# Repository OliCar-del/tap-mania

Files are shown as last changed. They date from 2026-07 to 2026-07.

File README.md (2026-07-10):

# tap-mania

## Overview

**tap-mania** is a miniaturized arcade rhythm and dance game designed to be played with your fingers. Inspired by classic rhythm games like *Dance Dance Revolution*, *StepMania*, and *Guitar Hero*, tpmania brings the arcade experience to a desktop form factor.

Players follow rhythm cues displayed on a 16x4 LED matrix and must press the corresponding colored arcade buttons in time with the music. The game tracks your accuracy, calculates your score, and builds combo multipliers based on your timing.

## Features

* **Miniature Arcade Interface:** Four distinct arcade-style buttons (Red, Green, Blue, Yellow) with internal LED illumination, paired with a 16x4 RGB LED matrix to display incoming beats.
* **Standalone Gameplay:** Fully functional without a PC. Load your favorite `.wav` tracks and `.tsq` sequence files onto a microSD card, plug it in, and select your song using the built-in OLED display.
* **Audio Output:** Integrated 3.5mm audio jack with volume control, capable of driving standard 32-ohm headphones or speakers.
* **Dynamic Scoring & Combos:** Earn points based on timing accuracy (Perfect!, Good!, OK, Poor, Miss) and build up a combo counter for successive accurate hits.
* **Customizable Difficulty:** Connect the device to the tap-mania PC GUI to customize your timing windows (stored directly on the device's non-volatile memory).
* **Portable:** Powered by a rechargeable 3.7V LiPo battery with USB charging capabilities.

## Hardware Specifications

To build or understand the hardware architecture of tap-mania, the following core components are utilized:

* **Microcontroller / USB Interface:** Uses a primary MCU connected via a custom USB bridge (utilizing the `polyglot-turtle-xiao` firmware).
* **LED Matrix:** 16x4 WS2812B RGB LED matrix.
* **Buttons:** 4x illuminated arcade pushbuttons + dedicated control/navigation buttons (or optional rotary encoder/joystick).
* **Display:** OLED module for track selection and game statistics.
* **Storage:** MicroSD card module for reading audio (`.wav`) and beatmaps (`.tsq`).
* **Audio:** 16-bit / 44.1kHz (minimum) DAC for audio generation.
* **Power:** 3.7V LiPo battery with an integrated USB charging circuit.

## PC Companion Application

The tap-mania ecosystem includes a PC-based graphical user interface (GUI) that communicates with the device over USB.

**Using the GUI, you can:**

* **Manage Tracks:** Browse, add, and remove `.tsq` sequences and `.wav` audio files directly to/from the microSD card.
* **Tweak Game Settings:** Adjust the exact millisecond timing windows for scoring (e.g., changing a "Perfect!" window from the default 200ms). These settings are saved to the device's internal memory.
* **View Track Metadata:** Read song names, artists, difficulty levels, BPM, and track length.

## How to Play

1. **Select a Track:** Use the onboard navigation buttons and OLED screen to pick a song from the SD card.
2. **Watch the Matrix:** The 16x4 LED matrix will show colored indicators falling towards the bottom of the screen.
3. **Tap to the Beat:** When the colored indicators reach the bottom of the matrix, the corresponding arcade buttons will light up. Press the buttons to the beat!
4. **Hold Notes:** If the LEDs show white indicators, hold the corresponding button down for the duration of the note.

**Scoring System:**

* **Perfect!**: +50 points (Default: ±100ms)
* **Good!**: +20 points (Default: ±150ms)
* **OK**: +10 points (Default: ±200ms)
* **Poor**: 0 points (Default: ±250ms)
* **Miss**: -10 points (Missed entirely, or pressed outside windows)

*Note: Your score cannot drop below zero. Missing notes will reset your active combo counter.*

## Custom Sequences (.tsq Format)

tap-mania uses a custom, lightweight text format for its beatmaps (`.tsq`).

### File Structure

A `.tsq` file consists of a header and a sequence body.

```text
Name: Song Title
Artist: Artist Name
BPM: 120
Difficulty: HARD
Offset: 500
---

```

* **BPM** must be between 90 and 220.
* **Difficulty** and **Offset** (delay in ms before the first beat) are optional.

### Sequence Data

Following the `---` divider, the beatmap uses a simple grid layout representing the 4 buttons (Red, Green, Blue, Yellow).

* `0` = No press
* `1` = Tap
* `2` = Hold (Hold starts on the first `2` and releases on the final `2` in a column)

Sequences are grouped into "bars" of 4 rows (or 8 rows for half-beats), separated by commas.

```text
1000
0100
0010
0001
,
2000
2000
0000
0000
;

```

*The file must end with a semicolon (`;`). Any audio file associated with the beatmap must share the exact same filename (e.g., `song.tsq` and `song.wav`) and be placed on the SD card.*

> ## Deep Dive Documentation
If you are looking to understand the internal workings of tap-mania, modify the codebase, or review the hardware design, please refer to our detailed documentation:

* 🧠 [Software Architecture & Execution Flow](ARCHITECTURE.md) - Details on the internal state machine, FatFs implementation, scoring logic, and hardware abstraction.
* ⚡ [Hardware & PCB Design](HARDWARE.md) - Details on the Altium schematics, power delivery (LiPo/USB), and signal routing.

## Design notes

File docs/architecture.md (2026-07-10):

---

# Architecture and Code Execution Summary

## 1. System Architecture Overview

The firmware is designed for an **STM32L433** microcontroller (configured via STM32CubeMX/IDE and built using a CMake workflow). It functions as a real-time embedded system that bridges low-latency hardware peripherals (timers, audio generation, button interrupts, and addressable LEDs) with a file system layer for standalone game execution, alongside a USB serial command link for configuration management.

```
                  +---------------------------------------+
                  |               Main Loop               |
                  |     (Game States, Menu, Execution)     |
                  +-------------------+-------------------+
                                      |
         +----------------------------+----------------------------+
         |                            |                            |
         v                            v                            v
+-----------------+          +-----------------+          +-----------------+
| System Drivers  |          |  Game Modules   |          | Data/Interfaces |
| - Audio (SAI)   |          | - TSQ Parser    |          | - FatFs (SD)    |
| - ARGB Matrix   |          | - Hit Scoring   |          | - Flash Storage |
| - Debounce/Int  |          | - State Control |          | - USB Serial    |
+-----------------+          +-----------------+          +-----------------+

```

---

## 2. Code Modules & Component Breakdown

### Core Game Engine & Parsing

* **`tsq_parser.c` / `tsq_parser.h**`
Responsible for streaming and parsing the custom `.tsq` rhythm sequence text files from the filesystem. It parses the metadata header (Name, Artist, BPM, Difficulty, and Beat Offset) and sequentially processes bars of row strings (`0`, `1`, `2`) to interpret taps, multi-presses, and hold notes.
* **`game_state.c` / `game_state.h**`
Manages the primary operational state machine of the machine (e.g., `MENU`, `SONG_SELECT`, `PLAYING`, `RESULTS_SCREEN`). It handles transitions, restarts, and game over sequences.
* **`scoring.c` / `scoring.h**`
Processes timing parameters down to the millisecond. When a hardware input event triggers, this module calculates the delta between the ideal beat-time and the actual player button press, mapping it to specific accuracy classifications (*Perfect!*, *Good!*, *OK*, *Poor*, *Miss*) and updates the total score and combo counters.

### Hardware Interface & Drivers

* **`audio.c` / `audio.h**`
Controls the monoaural audio stream. It interacts with the audio subsystem (likely utilizing the Serial Audio Interface — SAI or DAC via DMA) to read `.wav` data structures from the storage media, handling the configured audio latency offsets to match physical beats perfectly.
* **`ARGB.c` / `ARGB.h` & `led_display.c` / `led_control.c**`
Provides an optimized low-level driver for the addressable 16x4 WS2812B RGB LED matrix. It converts structural step paths into timed NRZ serial signals (often over SPI or TIM+DMA) to animate oncoming steps down the lane while dynamically lighting up the internal button LEDs.
* **`SH1106.c` / `SH1106.h` & `fonts.c**`
A hardware display driver targeting the I2C/SPI based SH1106 OLED module. It handles character arrays and coordinate plotting for system menus, song selections, and operational statistics.
* **`button_handler.c`, `button_debounce.c`, `config_input.c**`
Handles the asynchronous input processing. Pin interrupts generated by the four primary illuminated arcade switches and auxiliary controls are debounced using soft timers before being dispatched to the step engine.

### Subsystems & Connectivity

* **`sd_card_utils.c` / `sd_card_detect.c**`
Integrates the **FatFs** middleware platform directly above hardware SPI/SDMMC layers to interface reliably with external microSD cards containing song packs.
* **`config_storage.c`**
Implements a persistent storage system to save personalized device configurations (like customized user timing windows between 1ms and 500ms) within the STM32's internal non-volatile Flash memory pages.
* **`command_handler.c` / `uart_debug.c**`
Processes incoming serial streams passing through the USB interface (interfacing with the external USB microcontroller bridge). It maps PC-side adjustments into executable variables, allowing communication with the companion configuration GUI application.

---

## 3. Firmware Execution Flow

The program life cycle maps into three operational phases:

### Phase A: Initialization

1. **System Init:** Hardware abstraction layers (`HAL_Init`) configure internal phase-locked loops (PLLs) to supply stable clock lines across communication lines and compute registers.
2. **Peripheral Init:** Resets and schedules interfaces for internal systems (FatFs for SD card access, I2C/SPI for the SH1106 OLED, Timer channels for PWM/DMA LED patterns, and sound peripherals).
3. **Config Extraction:** Reads the internal Flash non-volatile space to extract customized game latency parameters. If blank, it initializes system default timings.
4. **Storage Verification:** Attempts to mount the microSD interface. If the card is missing or corrupted, a critical alert prints directly to the display loop.

### Phase B: Game Loop Execution

Once running, the main loop continually tracks operational events:

* **State Control:** Monitors current selections. If navigating menus, it decodes button ticks to cycle through parsed song variables.
* **Rhythm Mode Processing:** Upon starting a track, the processor synchronizes audio tracks with a master tick timer. The engine matches the song's BPM to periodically step row data forward, moving rows across the 16x4 matrix.
* **The Beat LED Window:** A software event schedules the hardware Beat LED to flash precisely `50ms` before the beat hits, cutting power `50ms` afterward.
* **Input Capture:** If a player triggers a button, an interrupt logs a timestamp. The delta between this click and the current track timing index is measured by `scoring.c` to assign score weightings instantly.

### Phase C: Communication & Interventions

* **UART Intercepts:** Asynchronous USB data packets from the PC GUI drop into ring buffers. `command_handler.c` executes these actions out of the game's critical loop (e.g., retrieving configuration lists or committing new timing windows directly to Flash).

---

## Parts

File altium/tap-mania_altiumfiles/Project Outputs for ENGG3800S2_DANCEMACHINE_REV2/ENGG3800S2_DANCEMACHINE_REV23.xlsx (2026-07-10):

Designator | Description | Quantity | Price each | Total price | Manufacturer | Manufacturer # | Supplier | Supplier # | RoHS link
U1 | 0.9-5V Step down DC/DC module | 1 | $4.74 | $4.74 | Murata Power Solutions | OKL-T/1-W12N-C | Digikey | 811-2260-1-ND | https://www.digikey.com.au/product-detail/en/murata-power-solutions-inc/OKL-T-1-W12N-C/811-2260-1-ND/2605211
U2 | Global shutter CMOS sensor | 1 | $178.32 | $178.32 | On Semiconductor | NOIP1FN1300A-QTI | Mouser | 863-NOIP1FN1300A-QTI | https://au.mouser.com/ProductDetail/ON-Semiconductor/NOIP1FN1300A-QTI
C1, C2 | 0.1uF 0603 capacitor, X7R, 10% | 2 | $0.41 | $0.83 | Taiyo Yuden | TMF107B7104KAHT | Mouser | 963-TMF107B7104KAHT | https://au.mouser.com/ProductDetail/Taiyo-Yuden/TMF107B7104KAHT
 |  |  | Total: | $183.89

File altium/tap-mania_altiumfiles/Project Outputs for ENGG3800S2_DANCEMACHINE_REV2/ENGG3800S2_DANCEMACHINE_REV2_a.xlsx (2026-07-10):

Comment | Description | Designator | Footprint | LibRef | Quantity
SEEEDUINO | SAMD21 Microcontroller Development Board 0.0327MHz/48MHzCPU 32KB RAM 256KB Flash | *1 | XIAO - 6mm annular | SEEEDUINO | 1
0.1uF | Capacitor CAP CER 0.1UF 25V X7R 0402 CL05B104KA5NNNC | C1, C2, C3, C4, C5, C12, C13, C15, C16, C17, C19, C25, C37, C38, C39, C40, C41, C42 | CAPC1005X55N | CL05B104KA5NNNC | 19
CAP/0603 | Ceramic Capacitor;16V;X7R;0603;, Ceramic Capacitor;50V;C0G;0603; 100pF, Ceramic Capacitor;25V;X7R | C6, C8, C9, C10, C12, C14, C16 | CAP/0603 | 07.0043, 07.0138, 07.0772, 07.0053 | 7
CAP/1206 | Ceramic Capacitor;10V;X7R;1206, Ceramic Capacitor;25V;X5R; | C7, C11, C13, C15, CBATT1, CIN1, CSYS1 | CAP/1206 | 07.0581, 07.0752 | 7
4.7uF | 860020672008 WCAP-ATG5 Aluminum Electrolytic Capacitors860020672008 | C14 | WCAP-ATG5_D5H11 | CMP-03913-53914231-1 | 1
1uF | Capacitor 1 µF ±10% 25V Ceramic Capacitor X7R 0603 (1608 Metric) CL10B105KA8NNNC | C17, C18, C21 | CAPC1608X90N | CL10B105KA8NNNC | 4
10nF ±10% 16V X7R | Capacitor 10000 pF ±10% 16V Ceramic Capacitor X7R 0603 (1608 Metric) ETSG 64-12-01 C0603C103K4RECTU | C19 | C0603 | C0603C103K4RECTU | 1
0.1 uF, +/- 10%, 50 V | Chip Capacitor, 0.1 uF, +/- 10%, 50 V, -55 to 125 degC, 0603 (1608 Metric), RoHS, Tape and Reel | C20, C22 | CAPC1608X90X35ML10T15 | CMP-2100-03643-1 | 2
10UF 16V X7R | CAP CER 10UF 16V X7R 0805 CL21B106KOQNNNE | C21, C24, C36 | FP-CL21B106KOQNNNE-MFG | CMP-2000-06106-2 | 3
1 µF ±10% 25V | Capacitor 1 µF ±10% 25V Ceramic Capacitor X7R 0603 (1608 Metric) CL10B105KA8NNNC | C23 | CAPC1608X90N | CL10B105KA8NNNC | 1
I2C OLED Display | OLED_I2C_4pinHEADER Large clear space | DISP1 | OLED_I2C_4pinHEADER | OLED_I2C_4pinHEADER | 1
0ZCG0300FF2B | Fuse | F1 | FUSC4632X155N | 0ZCG0300FF2B | 1
FBMH1608HM601-T | Ferrite Bead | FB1 | BEADC1608X90N | FBMH1608HM601-T | 1
Fiducial Mark | Small 1mm/40mil pad with 40mm soldermask clearance | FID1, FID2, FID3, FID4 | FIDUCIAL_SMALL | FIDUCIAL_SMALL | 4
Mounting Hole | M3 Mounting hole (3.4mm) | H1, H2, H3, H4 | M3_MOUNTING_HOLE_3_4_mm | M3_MOUNTING_HOLE | 4
TPD8S300ARUKR | Integrated Circuit | IC1 | QFN40P300X300X80-21N-D | TPD8S300ARUKR | 1
3220-10-0100-00 | Connector | J1 | 322010010000 | 3220-10-0100-00 | 1
JST_PH 2.0 Male Header | Male Header, Pitch 2 mm, 1 x 2 Position, Height 6 mm, Tail Length 3.4 mm, -25 to 85 degC, RoHS, Bulk B2B-PH-K-S(LF)(SN) | J1 | JST-B2B-PH-K-S_V | CMP-2000-05162-1 | 1
USB4105-GF-A | CONN RCPT USB2.0 TYPEC 5A | J2 | FP-USB4105-GF-A-MFG | CMP-245163-000001-1 | 1
0022285034 | Connector | J4 | 0022285034 | 0022285034 | 1
Micro SD | ETSG | J5 | SD CARD | SD_CARD_MICRO | 1
2.8mm Terminal | 2.8mm Spade Lug Connector 1742428-1, Connector 1742428-1 | J6, J7, J8, J9, J10, J11, J12, J13, J14 | 17424281 | 1742428-1 | 9
CONN HEADER VERT 1POS 2.54MM | CONN HEADER VERT 1POS 2.54MM PH1-01-UA | JAGND1, JPGND1 | FP-PH1-01-UA-MFG | CMP-42765-000003-1 | 2
2.2 uH, +/- 30%, 6.3 A | Semi-Shielded Power Inductor, 2.2 uH, +/- 30%, 6.3 A, -40 to 125 degC, 2-Pin SMD, RoHS, Tape and Reel SRN8040-2R2Y | L1 | BOUR-SRN8040_V | CMP-2000-07144-1 | 1
LED/SMD/0805 | LED;ºì¹â; | LED1 | LED/SMD/0805 | 19.0003 | 1
MCL-S270SRC | LED | LED2, LED4 | LEDC2012X90N | MCL-S270SRC | 2
61300211121 |  | P1, P2, P3, P4 | 61300211121 | CMP-1712-00002-6 | 6
4.7 KOhm, +/- 1%, 0.1 W | Chip Resistor, 4.7 KOhm, +/- 1%, 0.1 W, -55 to 155 degC, 0603 (1608 Metric), RoHS, Tape and Reel RC0603FR-074K7L | R1, R2, R3, R4, R5, R39, R40, R41, R42 | SURFM RESISTOR | 0805-R | 9
RES/0603 | Film Resistor;1%;, Film Resistor;5%;, Film Resistor;5%;1/10W, Film Resistor;1% | R6, R7, R8, R9, R10, R11, R12, R13, RH1, RISET1, RL1, ROLM1, RT1, RT2, RT3 | RES/0603 | 06.0160, 06.0112, 06.0691, 06.0129, 06.0284, 06.0015, 06.0148, 06.0177, 06.0182, 06.0039 | 15
30 Ohm | Resistor ERJPA3F30R0V 30 Ohms ±1% 0.333W, 1/3W Chip Resistor 0603 (1608 Metric) Automotive AEC-Q200, Pulse Withstanding Thick Film | R8, R12, R31, R32, R33 | RESC1608X55N | ERJPA3F30R0V | 5
510 Ohm | RES Thick Film, 510Ω, 1%, 0.125W, 100ppm/°C, 0805 CRCW0805510RFKEA | R13, R43 | FP-CRCW0805-e3-IPC_B | CMP-2001-03989-2 | 2
5.1K OHM 1% 1/10W | [NoValue], RES 5.1K OHM 1% 1/10W 0603 RC0603FR-075K1L | R14, R15 | RESC1608X55X25ML10T15 | CMP-2000-04091-1 | 2
10kOhm | Resistor RES 10K OHM 5% 1/8W 0805 RC0805JR-0710KL | R14, R25, R26, R27, R28, R29, R30 | RESC2012X60N | RC0805JR-0710KL | 7
1 MOhms ±0.1% 0.125W | 1 MOhms ±0.1% 0.125W, 1/8W Chip Resistor 0805 (2012 Metric) Anti-Sulfur, Automotive AEC-Q200 Thin Film | R16 | RESC2012X50N | RG2012P-105-B-T5 | 1
100kΩ, 0.1%, 0.125W | RG2012P-104-B-T5Automotive Metal Thin Film Chip Resistor, 0805, 100kΩ, 0.1%, 25ppm/°C, 0.125W, 150V | R17, R41, R42 | FP-RG2012-IPC_B | CMP-2001-02710-2 | 3
1kΩ ±1% 0.125W | 1kΩ ±1% 0.125W 0603 High Power Anti-Sulfur Thin Film Chip Resistor RNCP0603FTD1K00 | R34 | FP-RNCP0603-IPC_A | CMP-26527-006179-1 | 1
330 Ohms ±1% 0.125W | RK73H1JTTD3300F 330 Ohms ±1% 0.125W, 1/8W Chip Resistor 0603 (1608 Metric) Automotive AEC-Q200 Thick Film | R35, R36, R37, R38 | RESC1608X55X30ML20T10 | CMP-2000-01422-1 | 4
90kOhm | Film Resistor;1%; RES/0603 MCT06030C9102FP500 | RILIM1 | RES/0603 | 06.0129 | 1
RES/1206 | Film Resistor;1% | RS1 | RES/1206 | 06.0564 | 1
Solder Bridge | Tension Fill Solder Bridge | SB1, SB2, SB3, SB4, SB7, SB8, SB9 | SOLDER BRIDGE OPEN SMALL | SOLDER_BRIDGE_TDROP | 9
1825910-6 | Tact Switch, SPST-NO, 0.05 A, -35 to 85 degC, 4-Pin THD, RoHS, Bulk | SW1, SW2, SW3, SW5, SW6 | TECO-1825910-6_V | CMP-1684-00021-1 | 5
JS5208 | Switch | SW4 | JS5208 | JS5208 | 1
DPST | SW-T2-3A-A-A2-M2 | SW7 | SWITCH_PANELMOUNT | SWITCH_PANEL MOUNT | 1
Small testpoint 40mil | 40mil circular pad no hole | TP1, TP2, TP3, TP4, TP5 | TEST_POINT_SMALL | TEST_POINT_SMALL | 5
MP2637 |  | U1 | QFN24/4X4 | MP2637 | 1
STM32L433CCT6 - 48LQFP | IC MCU 32BIT 256KB FLASH 48LQFP | U1 | FP-LQFP48-5B-MFG | CMP-12105-000047-1 | 1
AP2112K-3.3TRG1 | IC REG LINEAR 3.3V 600MA SOT25 | U2 | FP-SOT25-MFG | CMP-12756-000035-1 | 1
MAX98357AETE+T | IC AMP CLASS D MONO 3.2W 16TQFN | U3 | FP-T1633-4-IPC_B | CMP-05698-000018-1 | 1
SJ1-3513N | Undefined or Miscellaneous | U4 | SJ13513N - stubby silk | SJ1-3513N | 1

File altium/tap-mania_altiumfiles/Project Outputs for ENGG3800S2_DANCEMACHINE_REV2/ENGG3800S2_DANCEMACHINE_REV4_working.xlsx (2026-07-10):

Comment | Description | Designator | Footprint | LibRef | Quantity
NC |  | [NoValue], *? |  | NC | 10
0.1µF, ±10%, 25V, X7R | Capacitor CAP CER 0.1UF 25V X7R 0402 CL05B104KA5NNNC | C1, C2, C3, C4, C5, C28, C30, C37, C38, C39, C40, C41, C42 | CAPC1005X55N | CL05B104KA5NNNC | 13
NC(1µF, ±10%, 25V, X7R) | Ceramic Capacitor;16V;X7R;0603; | C6 | CAP/0603 | 07.0043 | 1
22µF, ±10%, 25V, X7R | Ceramic Capacitor;10V;X7R;1206, Ceramic Capacitor;10V;X7R;1206; 22µF, ±10%, 25V, X7R, Ceramic Capacitor;25V;X5R; | C7, C13, CBATT1, CIN1, CSYS1 | CAP/1206 | 07.0581, 07.0752 | 5
100pF, ±10%, 25V, X7R | Ceramic Capacitor;50V;C0G;0603; 100pF | C8 | CAP/0603 | 07.0138 | 1
1µF, ±10%, 25V, X7R | Ceramic Capacitor;16V;X7R;0603;, Ceramic Capacitor;25V;X7R | C9, C12 | CAP/0603 | 07.0043, 07.0772 | 2
NC (10µF, ±10%, 25V, X7R) | Ceramic Capacitor;25V;X7R, Ceramic Capacitor;16V;X7R;0603; NC (22µF, ±10%, 25V, X7R) | C10, C14 | CAP/0603 | 07.0772, 07.0043 | 2
NC (0.1µF, ±10%, 25V, X7R) | Ceramic Capacitor;25V;X5R; | C11 | CAP/1206 | 07.0752 | 1
NC (1µF, ±10%, 25V, X7R) | Ceramic Capacitor;10V;X7R;1206 | C15 | CAP/1206 | 07.0581 | 1
100nF, ±10%, 25V, X7R | Ceramic Capacitor;16V;X7R;0603;100nF, ±10%, 25V, X7R | C16 | CAP/0603 | 07.0053 | 1
1μF, ±10%, 25V, X7R | Capacitor 1 µF ±10% 25V Ceramic Capacitor X7R 0603 (1608 Metric) CL10B105KA8NNNC | C17, C18 | CAPC1608X90N | CL10B105KA8NNNC | 2
10nF, ±10%, 25V, X7R | Capacitor 10000 pF ±10% 16V Ceramic Capacitor X7R 0603 (1608 Metric) ETSG 64-12-01 C0603C103K4RECTU | C19 | C0603 | C0603C103K4RECTU | 1
0.1µF, ±10%, 25V, X7R | Chip Capacitor, 0.1 uF, +/- 10%, 50 V, -55 to 125 degC, 0603 (1608 Metric), RoHS, Tape and Reel | C20 | CAPC1608X90X35ML10T15 | CMP-2100-03643-1 | 1
10µF, ±10%, 25V, X7R | CAP CER 10UF 16V X7R 0805 CL21B106KOQNNNE | C21, C36 | FP-CL21B106KOQNNNE-MFG | CMP-2000-06106-2 | 2
10μF, ±10%, 25V, X7R | CAP CER 10UF 16V X7R 0805 CL21B106KOQNNNE | C24 | FP-CL21B106KOQNNNE-MFG | CMP-2000-06106-2 | 1
0.1μF, ±10%, 25V, X7R | Capacitor CAP CER 0.1UF 25V X7R 0402 CL05B104KA5NNNC 0402, Capacitor CAP CER 0.1UF 25V X7R 0402 CL05B104KA5NNNC | C25, C27, C31, C33, C35 | CAPC1005X55N | CL05B104KA5NNNC | 5
0.1F, ±10%, 25V, X7R | Capacitor CAP CER 0.1UF 25V X7R 0402 CL05B104KA5NNNC | C26 | CAPC1005X55N | CL05B104KA5NNNC | 1
4.7uF, 20%, 50V, Alu | 860020672008 WCAP-ATG5 Aluminum Electrolytic Capacitors860020672008 | C29 | WCAP-ATG5_D5H11 | CMP-03913-53914231-1 | 1
1µF, ±10%, 25V, X7R | Capacitor 1 µF ±10% 25V Ceramic Capacitor X7R 0603 (1608 Metric) CL10B105KA8NNNC | C32, C34 | CAPC1608X90N | CL10B105KA8NNNC | 2
I2C OLED Display | OLED_I2C_4pinHEADER Large clear space | DISP1 | OLED_I2C_4pinHEADER | OLED_I2C_4pinHEADER | 1
6V 3A PTC Resettable Fuse | Polymeric PTC Resettable Fuse 6V 3 A Ih Surface Mount 1812 (4532 Metric), Concave | F1 | FUSC4632X155N | 0ZCG0300FF2B | 1
600 Ohms@100 MHz, 900mA | 600 Ohms @ 100 MHz 1 Power Line Ferrite Bead 0603 (1608 Metric) 900mA 170mOhm | FB1 | BEADC1608X90N | FBMH1608HM601-T | 1
Fiducial Mark | Small 1mm/40mil pad with 40mm soldermask clearance | FID1, FID2, FID3, FID4, FID5, FID6 | FIDUCIAL_SMALL | FIDUCIAL_SMALL | 6
Mounting Hole | M3 Mounting hole (3.4mm) | H1, H2, H3, H4 | M3_MOUNTING_HOLE_3_4_mm | M3_MOUNTING_HOLE | 4
BOLT, M3 x 10mm, NYLON |  | HW1, HW2, HW5, HW6 |  | M3_SCREW | 4
BOLT, M3 x 15mm, Zinc Plated Steel |  | HW3, HW4, HW7, HW8 |  | M3_SCREW | 4
NUT M3, NYLON |  | HW9, HW10, HW13, HW14 |  | NUT | 4
NUT M3, Zinc Plated Steel |  | HW11, HW12, HW15, HW16 |  | NUT | 4
NYLON Standoff M3, 10mm |  | HW17, HW18, HW19, HW20 |  | STANDOFF | 4
SPH-002T-P0.5S |  | HW21, HW22, HW27, HW28, HW29, HW30, HW31, HW32, HW37, HW38, HW39, HW40, HW45, HW46, HW47, HW48, HW81, HW82, HW83, HW84, HW85, HW86, HW87, HW88, HW89, HW90, HW91, HW92, HW93, HW94 |  | SPH-002T-P0.5S | 30
JST LTO-1.0T-110N-8 | JST LTO Uninsulated Female Spade Connector / Receptacle / 2.8 x 0.5mm Tab Size | HW23, HW24, HW25, HW26, HW33, HW34, HW35, HW36, HW41, HW42, HW43, HW44, HW49, HW50, HW51, HW52, HW65, HW66, HW67, HW68, HW69, HW70, HW71, HW72, HW73, HW74, HW75, HW76, HW77, HW78, HW79, HW80 |  | JST LTO-1.0T-110N-8 | 32
NYLON Spacer, 6.3mm, M3 | Spacer / Female - Female / Nylon / Hexagonal / M3 x 06.3 | HW53, HW54, HW55, HW56 |  | NYLON_STANDOFF_6_3_mm | 4
Velcro tape / Hook / 35mm | ETSG: 28-06-01 ACST : Tape / Velcro / Hook / 20mm / Price per cm | HW57 |  | VELCRO_HOOKS | 1
Velcro tape / Loops / 35mm | ETSG: 28-06-01 ACST : Tape / Velcro / Hook / 20mm / Price per cm | HW58 |  | VELCRO_LOOP | 1
KK Terminal | CONNECTOR : KK Style - Crimp Terminal Housing / 03 Way / 2.54mm Pitch / White ETSG 01-26-01 | HW59, HW60, HW61, HW62, HW63, HW64 |  | SPH-002T-P0.5S | 6
JST_PH 2.0 Male Header | Male Header, Pitch 2 mm, 1 x 2 Position, Height 6 mm, Tail Length 3.4 mm, -25 to 85 degC, RoHS, Bulk B2B-PH-K-S(LF)(SN), Male Header, Pitch 2 mm, 1 x 2 Position, Height 6 mm, Tail Length 3.4 mm, -25 to 85 degC, RoHS, Bulk B2B-PH-K-S(LF)(SN) CONNECTOR : JST PH - Top Entry Header / Thru Hole / 02 Way / 2.00mm Pitch ___ 08-51-01 | J2, P1 | JST-B2B-PH-K-S_V | CMP-2000-05162-1 | 3
3220-10-0100-00 | Connector | J3 | 322010010000 | 3220-10-0100-00 | 1
0022285034 | Connector | J4 | 0022285034 | 0022285034 | 2
Micro SD | ETSG | J5 | SD CARD | SD_CARD_MICRO | 1
61300211121 |  | JP1, JP2, JP3, JP4 | 61300211121 | CMP-1712-00002-6 | 4
Jumper Link / Single / Pitch 2.54mm | CONNECTOR : PCB Jumper Link / Single / Pitch 2.54mm / Black /shunt. 01-96-02 | JP5, JP6, JP7 |  | jumper_2.54mm | 3
2.2 uH, +/- 30%, 6.3 A | Semi-Shielded Power Inductor, 2.2 uH, +/- 30%, 6.3 A, -40 to 125 degC, 2-Pin SMD, RoHS, Tape and Reel SRN8040-2R2Y | L1 | BOUR-SRN8040_V | CMP-2000-07144-1 | 1
LED RED, Charging Indicator | LED;ºì¹â; LED/SMD/0805 | LED1 | LED/SMD/0805 | 19.0003 | 1
LED RED, Power Indicator | LED RED, Power Indicator, LED | LED2, LED4 | LEDC2012X90N | MCL-S270SRC | 2
LED RED, Beat Indicator | LED MCL-S270SRC | LED3 | LEDC2012X90N | MCL-S270SRC | 1
PHR-2 | CONN HOUSING PH 2POS 2MM WHITE | P2, P3 | FP-PHR-2-MFG | CMP-17439-000064-1 | 3
PHR-4 | CONN HOUSING PH 4POS 2MM WHITE | P4, P5, P6 | FP-PHR-4-MFG | CMP-17439-000059-1 | 6
B4B-PH-K-S(LF)(SN) | Male Header, Pitch 2 mm, 1 x 4 Position, Height 6 mm, Tail Length 3.4 mm, -25 to 85 degC, RoHS, Bulk, Male Header, Pitch 2 mm, 1 x 4 Position, Height 6 mm, Tail Length 3.4 mm, -25 to 85 degC, RoHS, Bulk CONNECTOR : JST PH - Top Entry Header / Thru Hole / 04 Way / 2.00mm Pitch. ETSG: 08-51-02 | P7, P8, P9 | JST-B4B-PH-K-S_V | CMP-2000-05165-1 | 6
22-01-3037 | CONN HOUS 3POS .100 W/RAMP/RIB | P10, P11 | FP-22-01-3037-MFG | CMP-04776-000467-1 | 4
CONN HEADER VERT 1POS 2.54MM | CONN HEADER VERT 1POS 2.54MM PH1-01-UA | P12, P13 | FP-PH1-01-UA-MFG | CMP-42765-000003-1 | 2
Arcade Button RED LED 30mm | Ausleaf. | PB1, PB5 |  | ARCADE_PUSHBUTTON | 2
Arcade Button GREEN LED 30mm | Ausleaf. | PB2, PB6 |  | ARCADE_PUSHBUTTON | 2
Arcade Button BLUE LED 30mm | Ausleaf. | PB3, PB8 |  | ARCADE_PUSHBUTTON | 2
Arcade Button YELLOW LED 30mm | Ausleaf. | PB4, PB7 |  | ARCADE_PUSHBUTTON | 2
BSS138 | MOSFET N-CH 50V 220MA SOT-23 | Q1, Q2, Q3, Q4 | FP-318-08-IPC_B | CMP-07173-000101-1 | 4
4.7Ω, ±5%, 1/8W | Chip Resistor, 4.7 KOhm, +/- 1%, 0.1 W, -55 to 155 degC, 0603 (1608 Metric), RoHS, Tape and Reel RC0603FR-074K7L | R1, R2, R3, R4, R5, R39, R40, R41, R42 | SURFM RESISTOR | 0805-R | 9
31.6kΩ, ±1%, 1/10W | Film Resistor;1%; | R6 | RES/0603 | 06.0160 | 1
10kΩ, ±1%, 1/10W | Film Resistor;1%; | R7 | RES/0603 | 06.0112 | 1
5.1kΩ, ±1%, 1/10W | Film Resistor;1%; | R8, RL1 | RES/0603 | 06.0691 | 2
15kΩ, ±5%, 1/8W | Film Resistor;1%; | R9 | RES/0603 | 06.0129 | 1
10kΩ, ±5%, 1/8W | Film Resistor;5%;, 10kΩ, ±5%, 1/8W | R10, R11 | RES/0603 | 06.0284 | 2
10kΩ, 1%, 0.125W | Film Resistor;5%; 10kΩ, 1%, 0.125W; 0603, Film Resistor;1%; 10kΩ, 1%, 0.125W; 0603, Film Resistor;1%; 10kΩ, 1%, 0.125W;0603 | R12, RT2, RT3 | RES/0603 | 06.0284, 06.0112 | 3
2kΩ, 5%, 0.125W | Film Resistor;5%;1/10W; 5kΩ, 5%, 0.125W 0603 | R13 | RES/0603 | 06.0015 | 1
330Ω, ±1%, 1/8W | RK73H1JTTD3300F 330 Ohms ±1% 0.125W, 1/8W Chip Resistor 0603 (1608 Metric) Automotive AEC-Q200 Thick Film | R14, R15, R21, R22, R35, R36, R38, R45 | RESC1608X55X30ML20T10 | CMP-2000-01422-1 | 8
1MΩ ±0.1% 0.125W | 1 MOhms ±0.1% 0.125W, 1/8W Chip Resistor 0805 (2012 Metric) Anti-Sulfur, Automotive AEC-Q200 Thin Film | R16 | RESC2012X50N | RG2012P-105-B-T5 | 1
100kΩ, 0.1%, 0.125W | RG2012P-104-B-T5Automotive Metal Thin Film Chip Resistor, 0805, 100kΩ, 0.1%, 25ppm/°C, 0.125W, 150V | R17 | FP-RG2012-IPC_B | CMP-2001-02710-2 | 1
30Ω, ±10%, 1/10W | Resistor ERJPA3F30R0V 30 Ohms ±1% 0.333W, 1/3W Chip Resistor 0603 (1608 Metric) Automotive AEC-Q200, Pulse Withstanding Thick Film | R18, R20, R31, R32, R33 | RESC1608X55N | ERJPA3F30R0V | 5
510Ω, 1%, 0.125W | RES Thick Film, 510Ω, 1%, 0.125W, 100ppm/°C, 0805 CRCW0805510RFKEA | R19, R23, R48 | FP-CRCW0805-e3-IPC_B | CMP-2001-03989-2 | 3
10kΩ, ±5%, 1/8W | Resistor RES 10K OHM 5% 1/8W 0805 RC0805JR-0710KL | R24 | RESC2012X60N | RC0805JR-0710KL | 1
10kΩ, ±1%, 1/10W | Resistor RES 10K OHM 5% 1/8W 0805 RC0805JR-0710KL | R25, R26, R27, R28, R29, R30 | RESC2012X60N | RC0805JR-0710KL | 6
1kΩ, ±1%, 1/8W | 1kΩ ±1% 0.125W 0603 High Power Anti-Sulfur Thin Film Chip Resistor RNCP0603FTD1K00 | R34 | FP-RNCP0603-IPC_A | CMP-26527-006179-1 | 1
10kΩ, ±1%, 1/8W | RES SMD 10KOHM 1% 1/8W 0603 MCT0603MC1002FP500 | R37, R43, R44, R46 | FP-MCT0603-MFG | CMP-02407-001346-1 | 4
NC (100kΩ, 0.1%, 0.125W) | RG2012P-104-B-T5Automotive Metal Thin Film Chip Resistor, 0805, 100kΩ, 0.1%, 25ppm/°C, 0.125W, 150V | R47 | FP-RG2012-IPC_B | CMP-2001-02710-2 | 1
21.5kΩ, ±5%, 1/8W | Film Resistor;1% | RH1 | RES/0603 | 06.0148 | 1
91kOhms ±1% 0.1W | 91 kOhms ±1% 0.1W, 1/10W Chip Resistor 0603 (1608 Metric) Anti-Sulfur Thin FilmMCT06030C9102FP500 | RILIM1 | RES/0603 | 06.0129 | 1
240kΩ, 1%, 1/8W | Film Resistor;1%; 240kΩ, 1%, 1/8W | RISET1 | RES/0603 | 06.0177 | 1
53.6kΩ, ±5%, 1/10W | Film Resistor;1% | ROLM1 | RES/0603 | 06.0182 | 1
0.02Ω, 1%, 0.25W | Film Resistor;1%; RES 0.02 OHM 1% 1/4W 1206; WSL1206R0200FEA | RS1 | RES/1206 | 06.0564 | 1
RES/0603 | Film Resistor;5%; | RT1 | RES/0603 | 06.0039 | 1
Solder Bridge | Tension Fill Solder Bridge | SB7, SB9 | SOLDER BRIDGE OPEN SMALL | SOLDER_BRIDGE_TDROP | 2
1825910-6 | Tact Switch, SPST-NO, 0.05 A, -35 to 85 degC, 4-Pin THD, RoHS, Bulk | SW1, SW2, SW3, SW5, SW6 | TECO-1825910-6_V | CMP-1684-00021-1 | 5
JS5208 | Switch | SW4 | JS5208 | JS5208 | 1
SW-T2-3A-A-A2-M2 | DPST SWITCH TOGGLE DPST 6A 125V SW-T2-3A-A-A2-M2 | SW7 | SWITCH_PCB_MOUNT | SWITCH_PANEL MOUNT | 1
Small testpoint 40mil | 40mil circular pad no hole | TP1, TP2, TP3, TP4, TP5 | TEST_POINT_SMALL | TEST_POINT_SMALL | 5
MP2637GR-Z |  | U1 | QFN24/4X4 | MP2637 | 1
AP2112K-3.3TRG1 | IC REG LINEAR 3.3V 600MA SOT25 AP2112K-3.3TRG1 | U2 | FP-SOT25-MFG | CMP-12756-000035-1 | 1
MAX98357AETE+T | IC AMP CLASS D MONO 3.2W 16TQFN | U3 | FP-T1633-4-IPC_B | CMP-05698-000018-1 | 1
SJ1-3513N | Undefined or Miscellaneous | U4 | SJ13513N - stubby silk | SJ1-3513N | 1
STM32L433CCT6 - 48LQFP | IC MCU 32BIT 256KB FLASH 48LQFP | U5 | FP-LQFP48-5B-MFG | CMP-12105-000047-1 | 1
SEEEDUINO | SAMD21 Microcontroller Development Board 0.0327MHz/48MHzCPU 32KB RAM 256KB Flash | U6 | XIAO - 6mm annular | SEEEDUINO | 1
WS2812B LED matrix, 16x4 |  | U7 |  | LED_MATRIX, LED_MATRIX_CUTOFF | 2

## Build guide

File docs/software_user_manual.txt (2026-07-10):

tpmania Configuration Tool – User Guide for GUI
Overview

This tool is used to configure the tpmania game device via a serial connection.
It provides the following main functions:

Configure and read scoring timing windows

Manage microSD card files (.tsq / .wav)

Convert Blackboard sample files into usable .tsq files

View serial console logs and debug messages

1. Serial Connection

Click “Refresh” to scan for available serial ports.

Select the correct port from the dropdown list (e.g., COM3).

Click “Connect” to open the serial connection.

The status label will turn green (“Connected”) on success.

If connection fails, an error message will appear.

2. Timing Windows Configuration

In the “Scoring Timing Windows (ms)” section, enter values for the four levels: Perfect, Good, OK, and Poor.

Click “Write to Device” to send the settings to the MCU.

The tool automatically divides each value by 2 before sending.

Any MCU response will be displayed in the right-side console.

Click “Read from Device” to read the current timing windows from the MCU.

Click “Restore Defaults” to reset all windows to default values.

3. microSD File Management

Click “SD Card Path” to select the microSD root directory, or choose a detected drive from the dropdown.

The listbox will display all .tsq and .wav files in the selected directory.

Use the following buttons to manage files:

Add File – Copy a file to the SD card folder

Delete File – Delete selected files

File Info – View metadata of a .tsq file (BPM, name, artist, difficulty, and estimated length)

Reload – Manually refresh the displayed list

4. Blackboard File Conversion

Click “Browse” to select a Blackboard .csv or .tsq file.

Click “Convert & Write to SD” to convert the file to .tsq format and save it to the SD card.

If the file is .csv, a minimal .tsq header (e.g., BPM and difficulty) is automatically added.

5. Serial Port Console

Type a command in the input box and press Enter or click “Send Command” to send it to the device.

The device’s responses and logs will appear in the black console window.

Click “List Serial” to display all available serial devices using PowerShell.

Notes

The serial baud rate is fixed at 115200.

If no response is received, ensure that the MCU sends a serial echo after processing commands.

Required Python packages: psutil, pyserial, and tkinter.

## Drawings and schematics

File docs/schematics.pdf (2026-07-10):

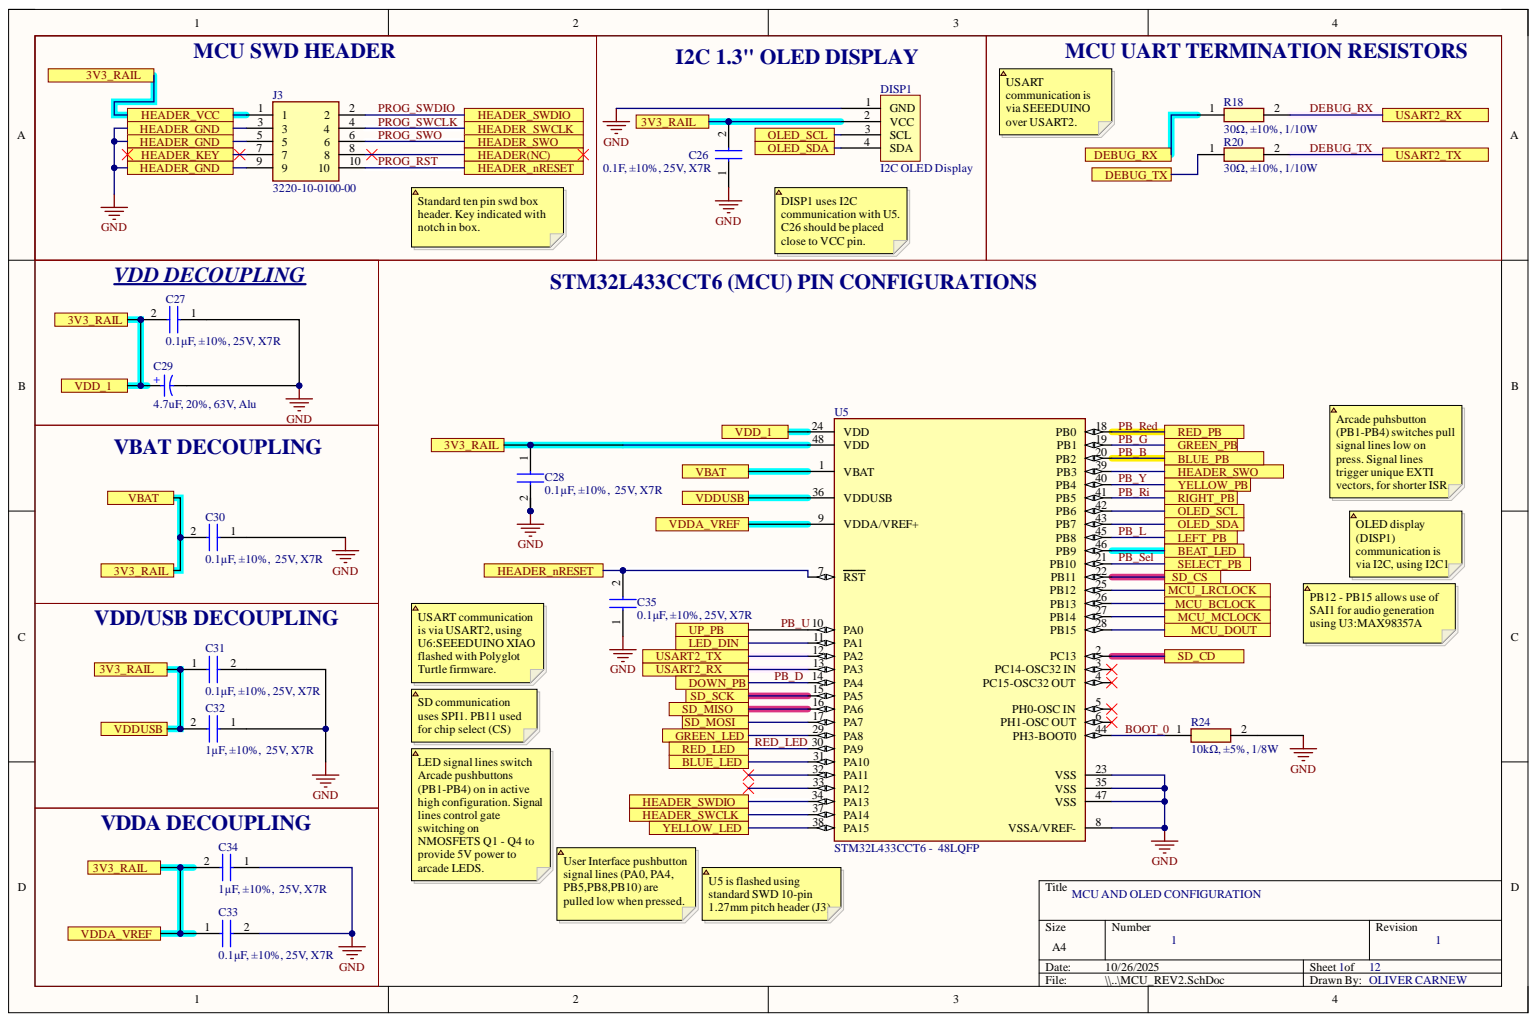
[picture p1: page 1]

MCU UART TERMINATION RESISTORS

Standard ten pin swd box
header. Key indicated with
notch in box.

DISP1 uses I2C
communication with U5.
C26 should be placed
close to VCC pin.

Arcade puhsbutton
(PB1-PB4) switches pull
signal lines low on
press. Signal lines
trigger unique EXTI
vectors, for shorter ISR.

VDD 48 | PB_G
VBAT 1 | PB_B

SD communication
uses SPI1. PB11 used
for chip select (CS)

LED signal lines switch
Arcade pushbuttons
(PB1-PB4) on in active
high configuration. Signal
lines control gate
switching on
NMOSFETS Q1 - Q4 to
provide 5V power to
arcade LEDS.

User Interface pushbutton
signal lines (PA0, PA4,
PB5,PB8,PB10) are
pulled low when pressed.

Title
MCU AND OLED CONFIGURATION

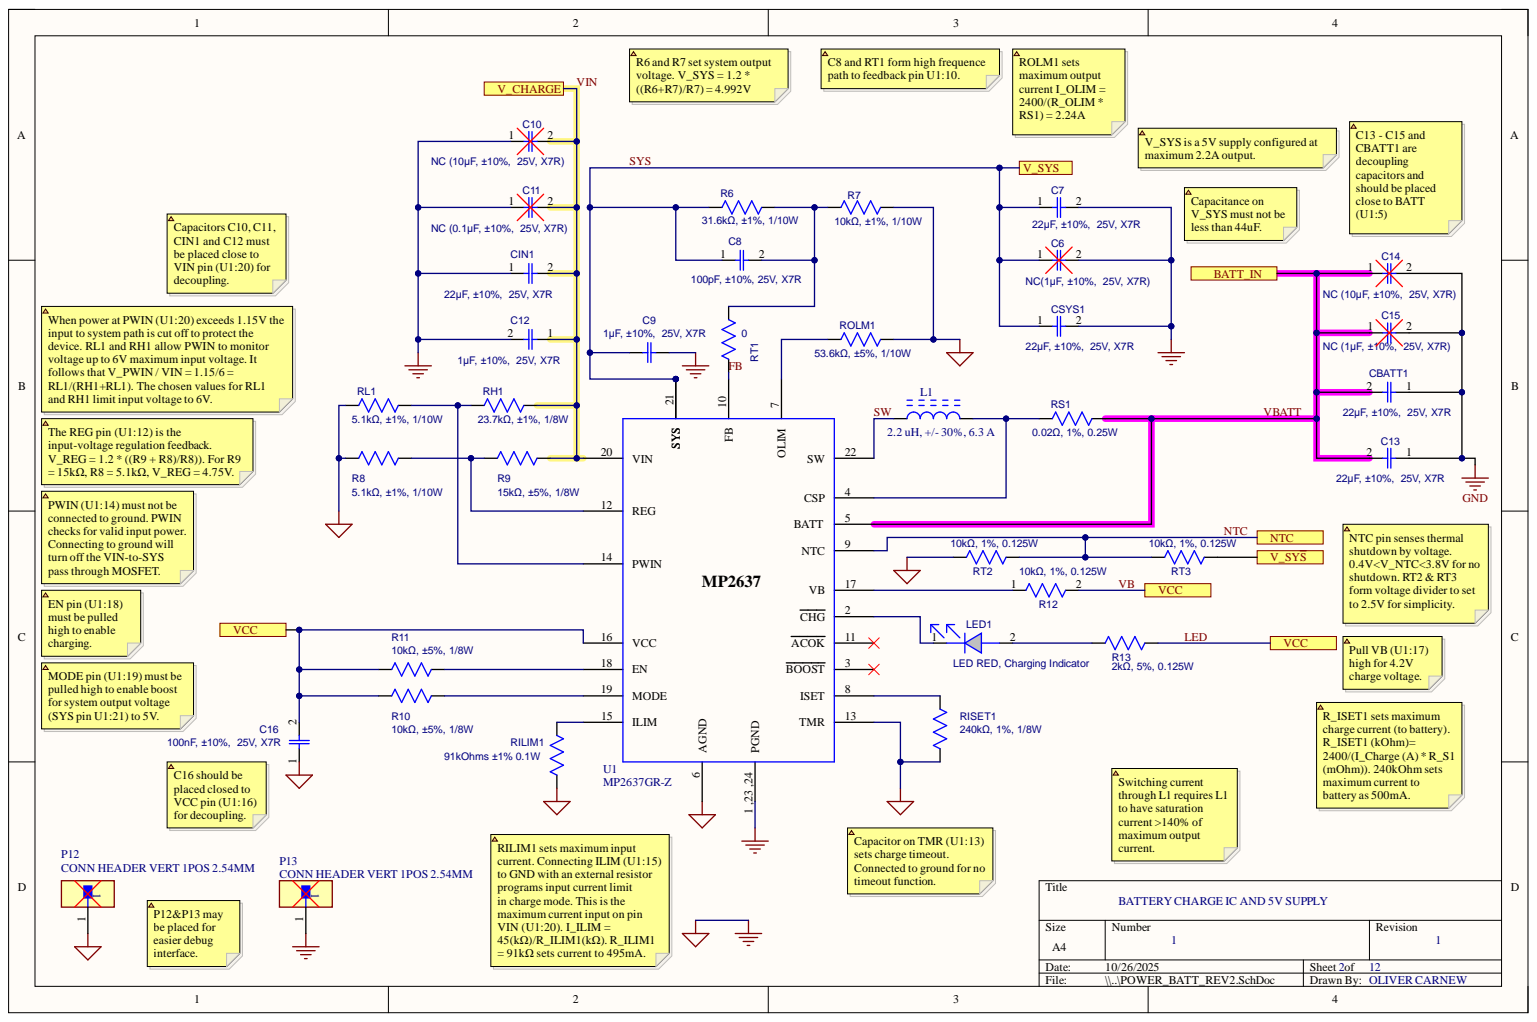
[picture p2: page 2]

C8 and RT1 form high frequence
path to feedback pin U1:10.

V_SYS is a 5V supply configured at
maximum 2.2A output.

Capacitors C10, C11,
CIN1 and C12 must
be placed close to
VIN pin (U1:20) for
decoupling.

When power at PWIN (U1:20) exceeds 1.15V the
input to system path is cut off to protect the
device. RL1 and RH1 allow PWIN to monitor
voltage up to 6V maximum input voltage. It
follows that V_PWIN / VIN = 1.15/6 =
and RH1 limit input voltage to 6V.

RL1/(RH1+RL1). The chosen values for RL1

The REG pin (U1:12) is the
input-voltage regulation feedback.
V_REG = 1.2 * ((R9 + R8)/R8)). For R9
= 15kΩ, R8 = 5.1kΩ, V_REG = 4.75V.

PWIN (U1:14) must not be
connected to ground. PWIN
checks for valid input power.
Connecting to ground will
turn off the VIN-to-SYS
pass through MOSFET.

NTC pin senses thermal
shutdown by voltage.
0.4V<V_NTC<3.8V for no
shutdown. RT2 & RT3
form voltage divider to set
to 2.5V for simplicity.

V_SYS

MODE pin (U1:19) must be
pulled high to enable boost
for system output voltage
(SYS pin U1:21) to 5V.

R_ISET1 sets maximum
charge current (to battery).
R_ISET1 (kOhm)=
2400/(I_Charge (A) *R_S1
(mOhm)). 240kOhm sets
maximum current to
battery as 500mA.

Capacitor on TMR (U1:13)
sets charge timeout.
Connected to ground for no
timeout function.

RILIM1 sets maximum input
current. Connecting ILIM (U1:15)
to GND with an external resistor
programsinput current limit
in charge mode. This is the
maximum current input on pin
VIN (U1:20). I_ILIM =
45(kΩ)/R_ILIM1(kΩ). R_ILIM1
= 91kΩ sets current to 495mA.

BATTERY CHARGE IC AND 5V SUPPLY

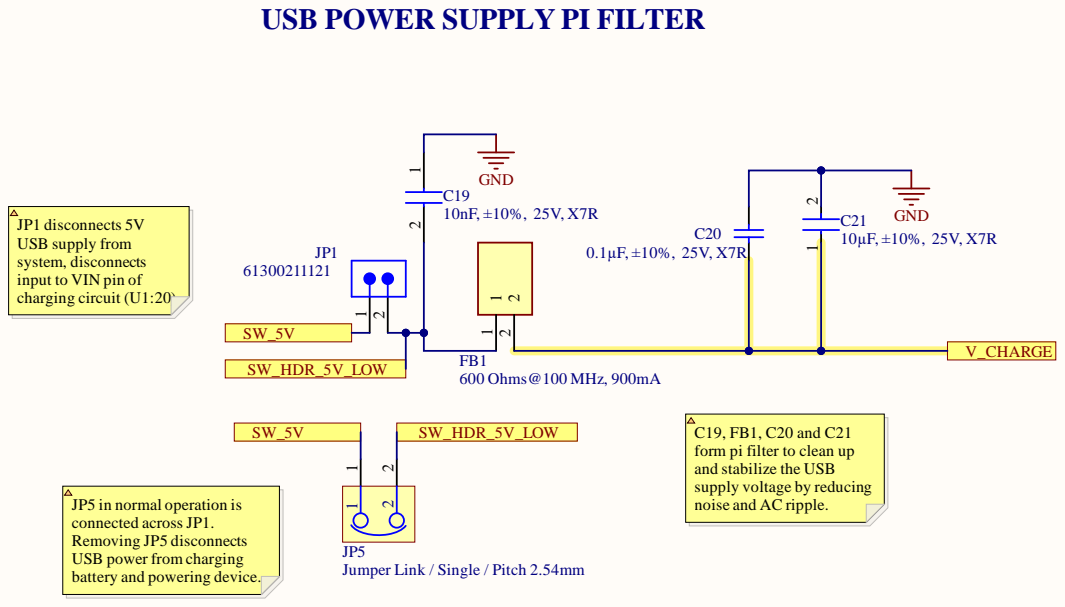
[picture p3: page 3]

USB POWER SUPPLY PI FILTER

JP1 disconnects 5V
USB supply from
system, disconnects
input to VIN pin of
charging circuit (U1:20).

C19, FB1, C20 and C21
form pi filter to clean up
and stabilize the USB
supply voltage by reducing

connected across JP1.
Removing JP5 disconnects
USB power from charging
battery and powering device.

Jumper Link / Single / Pitch 2.54mm

USB POWER SUPPLY INPUT FILTER

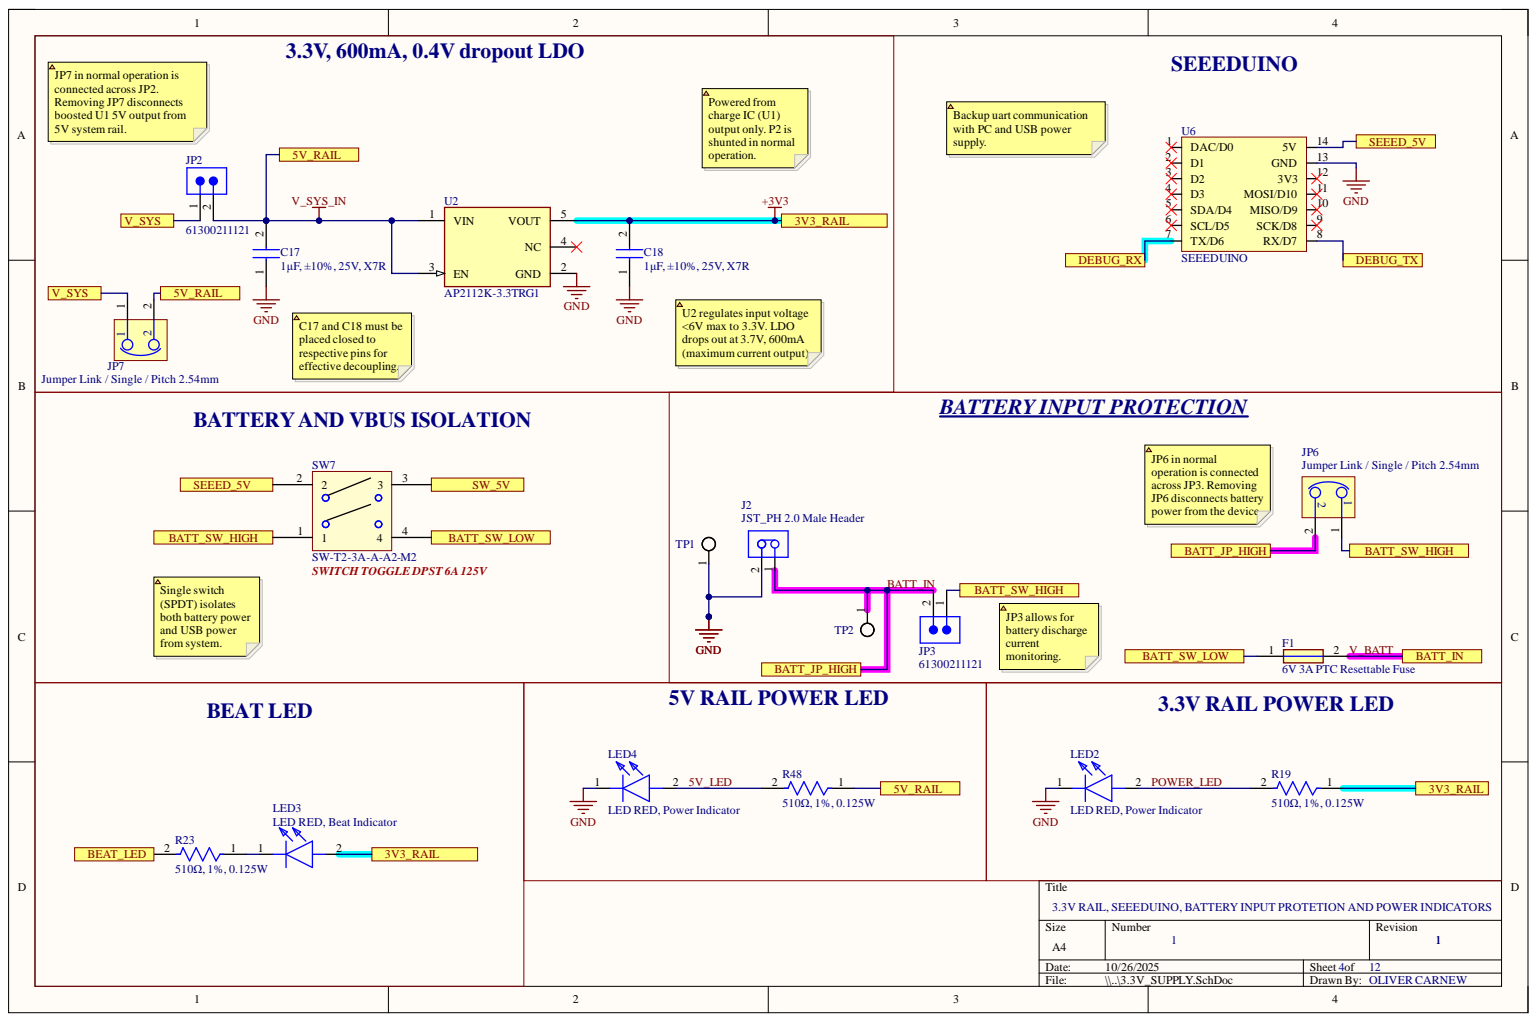
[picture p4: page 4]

JP7 in normal operation is
connected across JP2.
Removing JP7 disconnects
boosted U1 5V output from
5V system rail.

Backup uart communication
with PC and USB power
supply.

Jumper Link / Single / Pitch 2.54mm

JP6 in normal
operation is connected
across JP3. Removing
JP6 disconnects battery
power from the device.

LED3
LED RED, Beat Indicator

LED RED, Power Indicator

Title
3.3V RAIL, SEEEDUINO, BATTERY INPUT PROTETION AND POWER INDICATORS

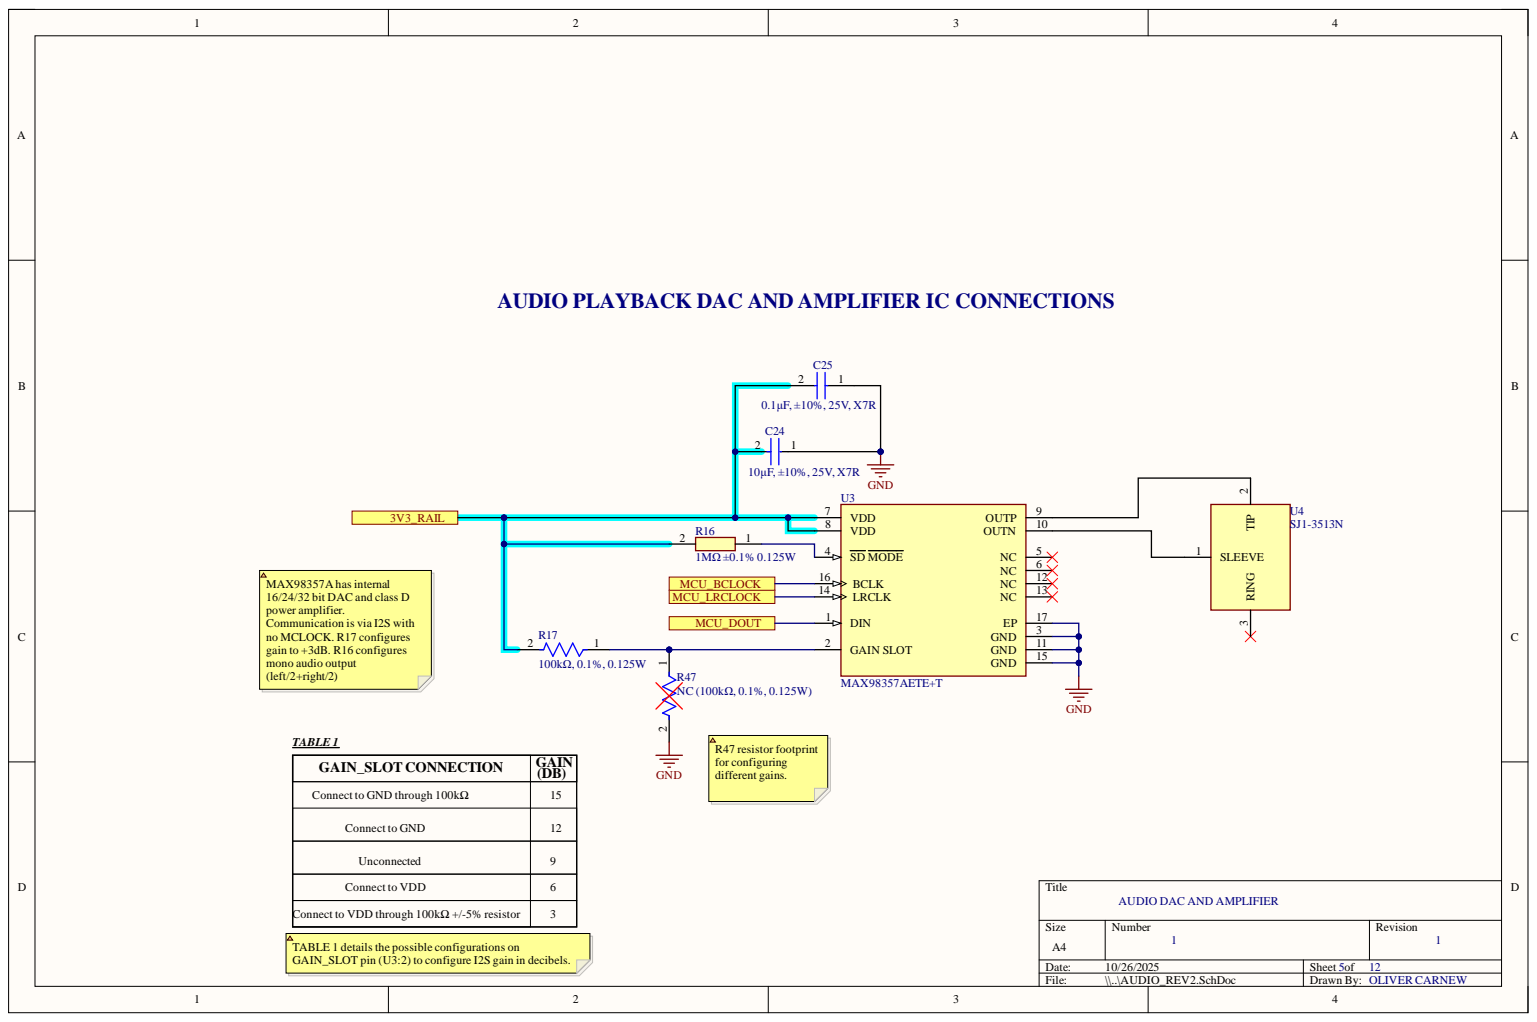
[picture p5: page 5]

AUDIO PLAYBACK DAC AND AMPLIFIER IC CONNECTIONS

2 1 R16 | VDD 8

MAX98357A has internal
16/24/32 bit DAC and class D
power amplifier.
Communication is via I2S with
no MCLOCK. R17 configures
gain to +3dB. R16 configures
mono audio output
(left/2+right/2)

GAIN_SLOT CONNECTION | GAIN (DB)

Connect to GND through 100kΩ | 15

Connect to GND | 12

Unconnected | 9

Connect to VDD | 6

AUDIO DAC AND AMPLIFIER

Connect to VDD through 100kΩ +/-5% resistor | 3

TABLE 1 details the possible configurations on
GAIN_SLOT pin (U3:2) to configure I2S gain in decibels.

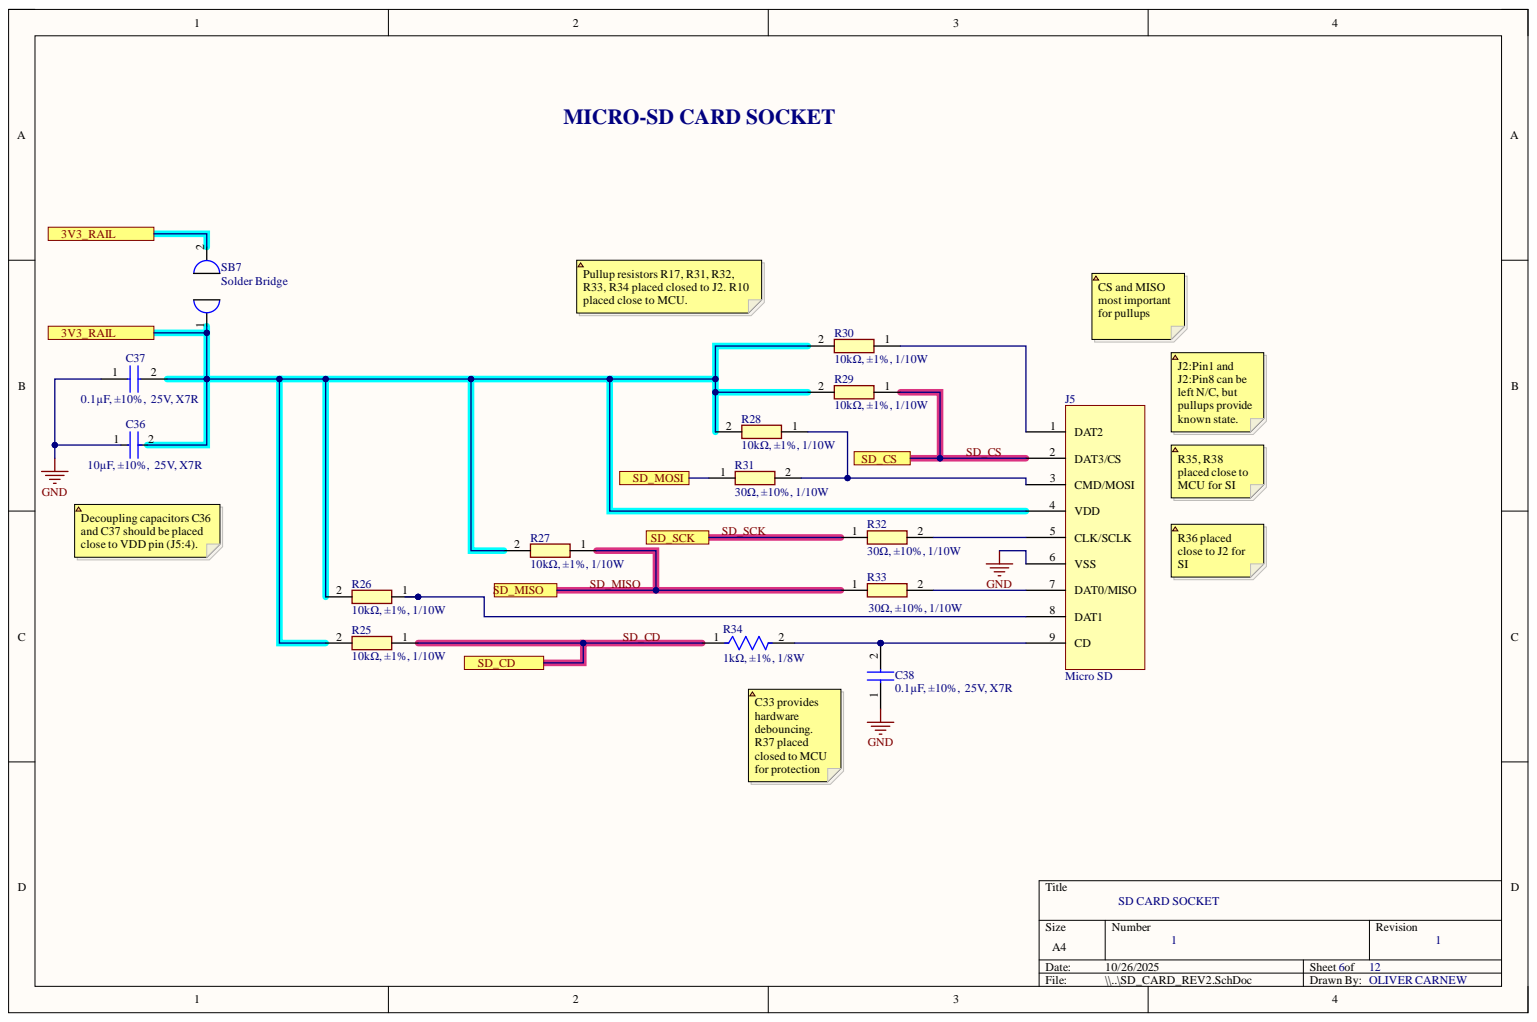
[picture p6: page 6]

MICRO-SD CARD SOCKET

Pullup resistors R17, R31, R32,
R33, R34 placed closed to J2. R10
placed close to MCU.

Decoupling capacitors C36
and C37 should be placed
close to VDD pin (J5:4).

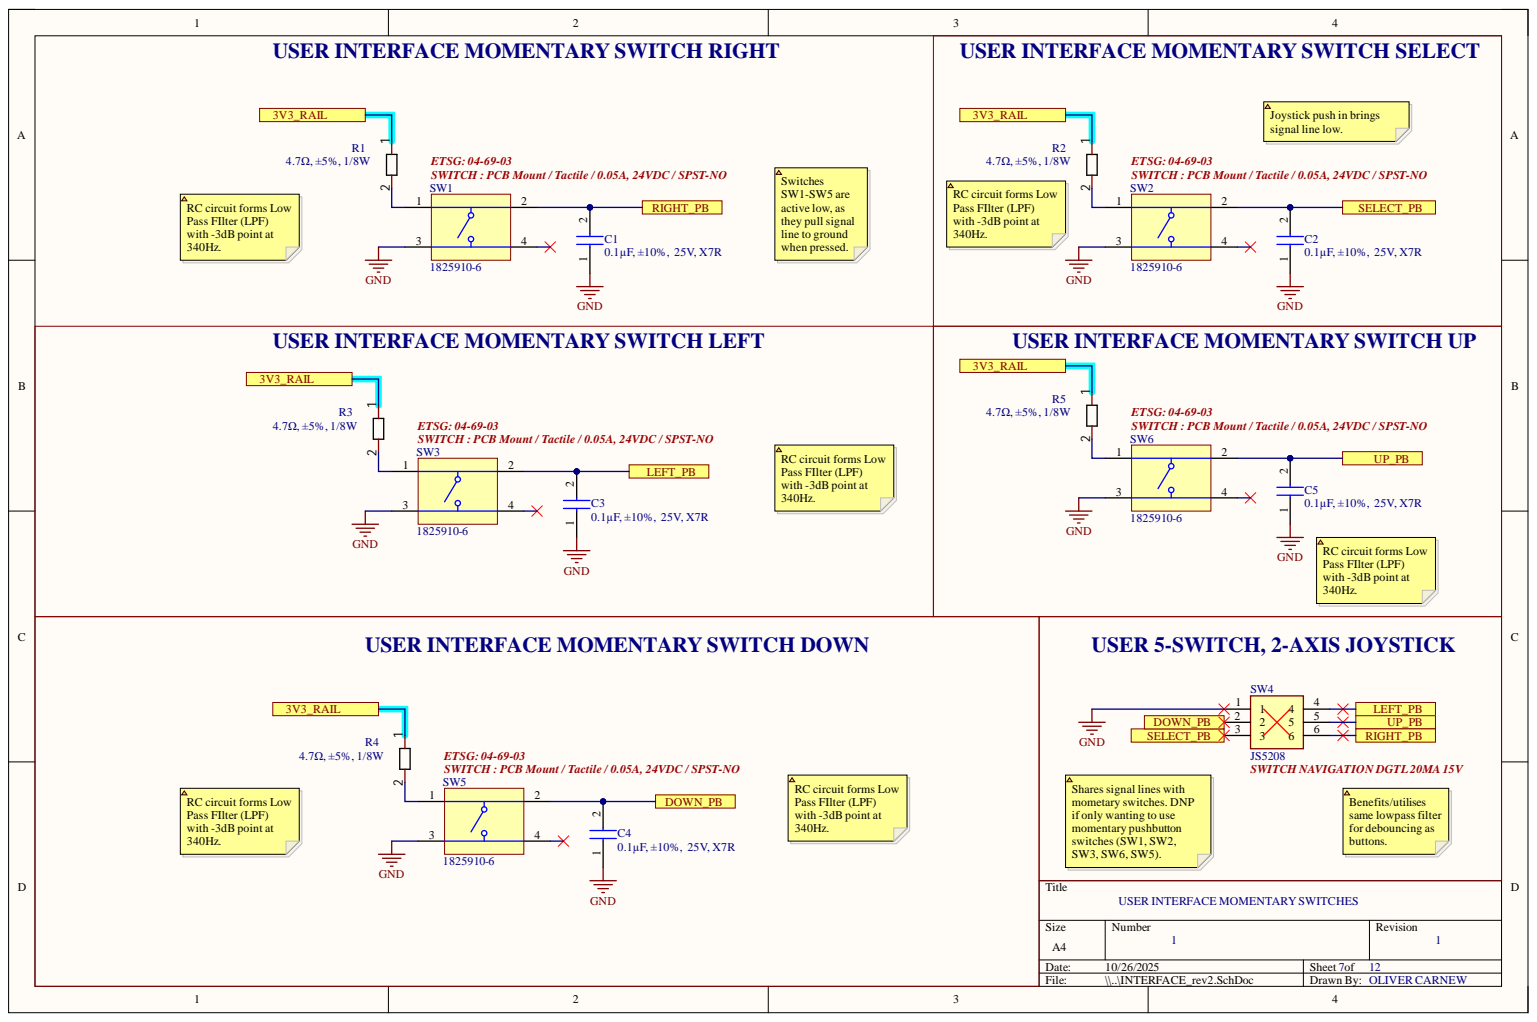
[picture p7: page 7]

USER INTERFACE MOMENTARY SWITCH RIGHT

USER INTERFACE MOMENTARY SWITCH SELECT

Joystick push in brings
signal line low.

ETSG: 04-69-03
SWITCH : PCB Mount / Tactile / 0.05A, 24VDC / SPST-NO

RC circuit forms Low
Pass FIlter (LPF)
with -3dB point at

USER INTERFACE MOMENTARY SWITCH LEFT

USER INTERFACE MOMENTARY SWITCH UP

USER INTERFACE MOMENTARY SWITCH DOWN

USER 5-SWITCH, 2-AXIS JOYSTICK
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

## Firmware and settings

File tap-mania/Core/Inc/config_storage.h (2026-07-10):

/**
 ******************************************************************************
 * @file           : config_storage.h
 * @brief          : Non-volatile configuration storage using Flash memory
 ******************************************************************************
 * @attention
 *
 * This module manages storage of configuration data (scoring windows) in
 * the device's Flash memory for persistence across power cycles.
 *
 * Flash usage: Last page of Flash (calculated dynamically based on device)
 * Typical addresses:
 *   - 256KB device (STM32L432KC): Page 127, 0x0803F800
 *   - 512KB device: Page 255, 0x0807F800
 *
 ******************************************************************************
 */
#ifndef CONFIG_STORAGE_H_
#define CONFIG_STORAGE_H_

#include "main.h"
#include "scoring.h"
#include <stdbool.h>
#include <stdint.h> // Defines uint32_t, int32_t, etc.

/* Configuration structure stored in Flash */
typedef struct {
    uint32_t magic; // Magic number for validation (0x544D4E50 = "TPMN")
    uint32_t version; // Config version (currently 1)
    ScoringWindows windows; // Scoring window configuration
    uint32_t checksum; // CRC32 checksum for validation
} ConfigData;

/* Flash memory configuration - updated for STM32L432KC with 256KB flash */
#define CONFIG_FLASH_PAGE 127 // Last page of 256KB Flash (0-127)
#define CONFIG_FLASH_ADDRESS 0x0803F800 // Start of last page for 256KB device
#define CONFIG_MAGIC 0x544D4E50 // "TPMN" in hex
#define CONFIG_VERSION 1

/* Flash size detection */
// #define FLASHSIZE_BASE          0x1FFF75E0          // Flash size register address for STM32L4
#define FLASH_BASE_ADDRESS 0x08000000 // Start of Flash memory
// #define FLASH_PAGE_SIZE         2048                // 2KB page size for STM32L4

/* Default scoring windows (from specification) */
#define DEFAULT_PERFECT_RADIUS_MS 100
#define DEFAULT_GOOD_RADIUS_MS 150
#define DEFAULT_OK_RADIUS_MS 200
#define DEFAULT_POOR_RADIUS_MS 250

/* Function prototypes */

/**
 * @brief Initialize configuration storage system
 *
 * Performs flash size detection and validates configuration address.
 * Checks if valid configuration exists in Flash.
 * If valid config found, loads it into scoring system.
 * If not, uses default values.
 *
 * @return true if valid config was loaded from Flash, false if using defaults
 */
bool Config_Init(void);

/**
 * @brief Load configuration from Flash into scoring system
 *
 * Reads configuration from Flash, validates it, and applies to scoring module.
 *
 * @return true if successful, false if Flash data invalid
 */
bool Config_Load(void);

/**
 * @brief Save current scoring windows to Flash
 *
 * Reads current windows from scoring module and writes to Flash memory.
 * Performs erase-program cycle on the config page.
 *
 * @return true if successful, false if Flash operation failed
 */
bool Config_Save(void);

/**
 * @brief Reset configuration to defaults
 *
 * Restores default scoring windows and optionally saves to Flash.
 *
 * @param save_to_flash If true, writes defaults to Flash immediately
 * @return true if successful
 */
bool Config_ResetToDefaults(bool save_to_flash);

/**
 * @brief Validate configuration data
 *
 * Checks magic number, version, window ordering, ranges, and checksum.
 * Also detects uninitialized flash (all 0xFF).
 *
 * @param config Pointer to configuration structure to validate
 * @return true if valid, false otherwise
 */
bool Config_Validate(const ConfigData* config);

/**
 * @brief Get pointer to current configuration in Flash
 *
 * @return Pointer to Flash-resident config structure (read-only)
 */
const ConfigData* Config_GetFlashData(void);

/**
 * @brief Calculate CRC32 checksum for configuration
 *
 * @param config Pointer to configuration structure
 * @return CRC32 checksum value
 */
uint32_t Config_CalculateChecksum(const ConfigData* config);

/**
 * @brief Check if Flash contains valid configuration
 *
 * @return true if valid config exists in Flash
 */
bool Config_IsValid(void);

/**
 * @brief Erase configuration from Flash
 *
 * WARNING: This erases the entire config page. Use with caution.
 *
 * @return true if successful
 */
bool Config_Erase(void);

/**
 * @brief Detect actual flash size from device information register
 *
 * Reads the FLASHSIZE register to determine the actual flash size
 * of the device in use.
 *
 * @return Flash size in kilobytes (e.g., 256 for 256KB device)
 */
uint32_t Config_GetFlashSize(void);

/**
 * @brief Validate that configuration address is within valid flash range
 *
 * Checks that CONFIG_FLASH_ADDRESS falls within the actual flash memory
 * of the device. This prevents hardfaults from accessing invalid addresses.
 *
 * @return true if address is valid, false if out of range
 */
bool Config_ValidateAddress(void);

/**
 * @brief Get detailed validation status string
 *
 * Provides human-readable description of configuration status.
 * Useful for debugging and user feedback.
 *
 * @return Pointer to status string
 */
const char* Config_GetStatusString(void);

#endif /* CONFIG_STORAGE_H */

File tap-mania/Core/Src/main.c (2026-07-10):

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
/* Includes ------------------------------------------------------------------*/
#include "main.h"
#include "fatfs.h"

/* USER CODE BEGIN Includes */
#include "ARGB.h"
#include "SH1106.h"
#include "button_debounce.h"
#include "button_handler.h"
#include "config_input.h"
#include "config_storage.h"
#include "ff.h"
#include "led_control.h"
#include "led_display.h"
#include "libs.h"
#include "scoring.h"
#include "sequence.h"
#include "tsq_parser.h"
#include <stdbool.h>
#include <stdio.h>
#include <string.h>
// New modular includes
#include "beat_event.h"
#include "command_handler.h"
#include "game_state.h"
#include "led_control.h"
#include "sd_card_detect.h"
#include "sd_card_utils.h"
#include "test_sequences.h"
#include "uart_debug.h"
/* USER CODE END Includes */

/* USER CODE BEGIN PD */
#define LED_ON_TIME_MS 100
#define INIT_DELAY_SHORT_MS 50
#define INIT_DELAY_LONG_MS 200
#define INIT_DELAY_VERY_LONG_MS 8000
#define TIM7_OVERFLOW_US 655360
/* USER CODE END PD */

I2C_HandleTypeDef hi2c1;

SAI_HandleTypeDef hsai_BlockA1;
DMA_HandleTypeDef hdma_sai1_a;

SPI_HandleTypeDef hspi1;

TIM_HandleTypeDef htim2;
TIM_HandleTypeDef htim6;
TIM_HandleTypeDef htim7;
DMA_HandleTypeDef hdma_tim2_ch2_ch4;

UART_HandleTypeDef huart2;
DMA_HandleTypeDef hdma_usart2_rx;

/* USER CODE BEGIN PV */
// Global variables shared across modules
volatile bool beat_event_flag = false;
volatile uint32_t last_beat_timestamp = 0;
volatile uint32_t beat_count = 0;
volatile uint16_t current_bpm = 30;
uint32_t sequence_length = 0;
volatile uint32_t tim7_overflow_count = 0;

// DMA UART Buffers
uint8_t uart_rx_buffer[UART_RX_BUFFER_SIZE];
uint8_t uart_tx_buffer[UART_TX_BUFFER_SIZE];
volatile uint32_t uart_rx_head = 0;
uint32_t uart_rx_tail = 0;
volatile uint8_t uart_tx_busy = 0;

// LED control
LEDControl led_control = {0};
uint32_t beat_led_on_tick = 0;
uint32_t beat_led_off_tick = 0;

// Legacy note event variables (kept for compatibility)
NoteEvent notes[MAX_NOTES];
int notes_head = 0, notes_tail = 0;
int32_t total_score = 0;
uint32_t odd_count = 0;
int selected_song = 0;
bool scrolled = false;
bool rightPressed = false;
bool selectedNewSong = false;

static bool config_menu_enabled = true; // Set to true to show config option
/* USER CODE END PV */

void SystemClock_Config(void);
static void MX_GPIO_Init(void);
static void MX_DMA_Init(void);
static void MX_USART2_UART_Init(void);
static void MX_TIM2_Init(void);
static void MX_TIM6_Init(void);
static void MX_SAI1_Init(void);
static void MX_TIM7_Init(void);
static void MX_I2C1_Init(void);
static void MX_SPI1_Init(void);
/* USER CODE BEGIN PFP */
void Update_BPM_Timer(uint16_t bpm);
uint32_t GetMicrosecondTimestamp(void);
/* USER CODE END PFP */

/* USER CODE BEGIN 0 */

/**
 * @brief Prepend config option to song list
 * This modifies tsqFiles to include a "CHANGE CONFIG->" entry at index 0
 */
void PrependConfigOption(char ****tsqFiles_ptr, int *tsqCount_ptr) {
  if (!config_menu_enabled)
    return;

  char ***tsqFiles = *tsqFiles_ptr;
  int tsqCount = *tsqCount_ptr;

  // Allocate new arrays with space for one extra entry
  char ***newTsqFiles = malloc(sizeof(char **) * 3);
  newTsqFiles[0] = malloc(sizeof(char *) * (tsqCount + 1)); // Names
  newTsqFiles[1] = malloc(sizeof(char *) * (tsqCount + 1)); // Artists
  newTsqFiles[2] = malloc(sizeof(char *) * (tsqCount + 1)); // Filenames

  // Add config option at index 0
  newTsqFiles[0][0] = malloc(strlen("CHANGE CONFIG->") + 1);
  strcpy(newTsqFiles[0][0], "CHANGE CONFIG->");

  newTsqFiles[1][0] = malloc(strlen("") + 1);
  strcpy(newTsqFiles[1][0], "");

  newTsqFiles[2][0] = malloc(strlen("__CONFIG__") + 1);
  strcpy(newTsqFiles[2][0], "__CONFIG__");

  // Copy existing songs starting at index 1
  for (int i = 0; i < tsqCount; i++) {
    newTsqFiles[0][i + 1] = malloc(strlen(tsqFiles[0][i]) + 1);
    strcpy(newTsqFiles[0][i + 1], tsqFiles[0][i]);

    newTsqFiles[1][i + 1] = malloc(strlen(tsqFiles[1][i]) + 1);
    strcpy(newTsqFiles[1][i + 1], tsqFiles[1][i]);

    newTsqFiles[2][i + 1] = malloc(strlen(tsqFiles[2][i]) + 1);
    strcpy(newTsqFiles[2][i + 1], tsqFiles[2][i]);
  }

  // Free old arrays (if needed - be careful with this based on your memory
  // management) In your case, you might want to keep the old arrays since
  // they're from SD card

  // Update pointers
  *tsqFiles_ptr = newTsqFiles;
  *tsqCount_ptr = tsqCount + 1;
}

/**
 * @brief Get microsecond timestamp using TIM7 with overflow handling
 */
uint32_t GetMicrosecondTimestamp(void) {
  uint32_t overflow_snapshot;
  uint16_t counter_snapshot;

  do {
    overflow_snapshot = tim7_overflow_count;
    counter_snapshot = TIM7->CNT;
    __DSB();
  } while (overflow_snapshot != tim7_overflow_count);

  return (overflow_snapshot * TIM7_OVERFLOW_US) + (counter_snapshot * 10);
}

/**
 * @brief  Calculates and updates the TIM6 period to match a given BPM.
 * @param  bpm: The desired beats per minute.
 * @retval None
 */
void Update_BPM_Timer(uint16_t bpm) {
  if (bpm > 0) {
    uint32_t timer_period = 600000 / bpm;
    __HAL_TIM_SET_AUTORELOAD(&htim6, timer_period - 1);
  }
}

/**
 * @brief  TIM6 Period Elapsed Callback (Metronome ISR).
 * @param  htim: TIM handle.
 * @retval None
 */
void HAL_TIM_PeriodElapsedCallback(TIM_HandleTypeDef *htim) {
  if (htim->Instance == TIM6) {
    last_beat_timestamp = GetMicrosecondTimestamp();
    beat_count++;
    beat_event_flag = true;
  } else if (htim->Instance == TIM7) {
    tim7_overflow_count++;
  }
}

/**
 * @brief UART TX Complete Callback
 */
void HAL_UART_TxCpltCallback(UART_HandleTypeDef *huart) {
  if (huart->Instance == USART2) {
    uart_tx_busy = 0;
  }
}

/**
 * @brief UART Error Callback
 */
void HAL_UART_ErrorCallback(UART_HandleTypeDef *huart) {
  if (huart->Instance == USART2) {
    HAL_UART_Receive_DMA(&huart2, uart_rx_buffer, UART_RX_BUFFER_SIZE);
    uart_tx_busy = 0;
  }
}
bool fillWavBuffer = false;
void HAL_SAI_TxCpltCallback(SAI_HandleTypeDef *hsai) {
  // myprintf("TXCallBack");
  fillWavBuffer = true;
}

/* USER CODE END 0 */

/**
 * @brief  The application entry point.
 * @retval int
 */
int main(void) {

  /* USER CODE BEGIN 1 */
  char uart_buf[256];
  int uart_buf_len;
  uint8_t selected_sequence = 0;

  FATFS FatFs;
  FIL fil;
  FRESULT fres;
  FileList fileList;
  TSQMetadata tsq_metadata;
  /* USER CODE END 1 */

  /* MCU Configuration--------------------------------------------------------*/

  /* Reset of all peripherals, Initializes the Flash interface and the Systick.
   */
  HAL_Init();

  /* Configure the system clock */
  SystemClock_Config();

  /* USER CODE BEGIN SysInit */
  HAL_Delay(INIT_DELAY_LONG_MS);
  /* USER CODE END SysInit */

  /* Initialize all configured peripherals */
  MX_GPIO_Init();
  MX_DMA_Init();
  MX_USART2_UART_Init();
  MX_TIM2_Init();
  MX_TIM6_Init();
  MX_SAI1_Init();
  MX_TIM7_Init();
  MX_FATFS_Init();
  MX_I2C1_Init();
  MX_SPI1_Init();
  /* USER CODE BEGIN 2 */

  // ONE-TIME HARDWARE & MODULE INITIALIZATION
  uint8_t sh1106InitRet = SH1106_Init();
  myprintf("sh1106InitRet = %d\r\n", sh1106InitRet);
  UART_StartDMAReception();
  uart_buf_len = sprintf(uart_buf, "\r\n\r\n=== tpmania v1.0 ===\r\n");
  UART_Transmit((uint8_t *)uart_buf, uart_buf_len);
  HAL_Delay(100);
  uart_buf_len = sprintf(uart_buf, "\r\n=== DMA UART INITIALIZED ===\r\n");
  UART_Transmit((uint8_t *)uart_buf, uart_buf_len);

  volatile uint32_t *stack_pointer = (uint32_t *)__get_MSP();
  safe_uart_puts("DEBUG: 5. Stack pointer: ");
  safe_uart_putnum((uint32_t)stack_pointer);
  safe_uart_puts("\r\n");
  HAL_Delay(INIT_DELAY_SHORT_MS);
  Safe_Stack_Fill();
  safe_uart_puts("DEBUG: 6. Stack pattern complete\r\n");
  HAL_Delay(INIT_DELAY_SHORT_MS);
  __HAL_TIM_CLEAR_FLAG(&htim6, TIM_FLAG_UPDATE);
  __HAL_TIM_CLEAR_FLAG(&htim2, TIM_FLAG_UPDATE);
  safe_uart_puts("DEBUG: 7. Timer flags cleared\r\n");
  HAL_Delay(INIT_DELAY_SHORT_MS);
  safe_uart_puts("DEBUG: 8. System ready message\r\n");
  safe_uart_puts("\r\n=== SYSTEM READY ===\r\n");
  safe_uart_puts("BPM: ");
  safe_uart_put_ulu(current_bpm);
  safe_uart_puts("\r\n");
  HAL_Delay(INIT_DELAY_SHORT_MS);

  // Initialize custom modules
  Scoring_Init();
  Config_Init();
  ButtonHandler_Init();
  Sequence_Init();
  InitLEDControl();
  HAL_GPIO_WritePin(BEAT_LED_GPIO_Port, BEAT_LED_Pin, GPIO_PIN_SET);

  myprintf("\r\n=== Initialising ARGB ===");
  ARGB_Init();

  ARGB_SetBrightness(ARGB_BRIGHTNESS);
  myprintf("\r\n=== ARGB INITIALISED w/ Brightness = %d ===", ARGB_BRIGHTNESS);
  myprintf("\r\nARR=%lu PSC=%lu DMA_state=%d hdma_cc2=%p",
           (unsigned long)TIM2->ARR, (unsigned long)TIM2->PSC,
           (int)HAL_DMA_GetState(&hdma_tim2_ch2_ch4),
           (void *)htim2.hdma[TIM_DMA_ID_CC2]);
  ARGB_SetBrightness(1);

  myprintf("\r\n=== Initialising SD CARD ===");
  myprintf("\r\nretUSER = %d", retUSER);
  HAL_Delay(1000);

  myprintf("\r\n>>>> Sending 80 clocks ===");
  sd_send_80_clocks();
  extern DSTATUS USER_SPI_initialize(BYTE);
  DSTATUS s = USER_SPI_initialize(0);
  myprintf("\r\nUSER_SPI_initialize -> 0x%02X\r\n", s);

  ChangeSystemState(SYSTEM_STATE_INIT);

  // ETHAN PV
  int horizontalOffset = 0;
  int tsqCount = 0;
  char ***tsqFiles;
  // NOTE: the sd card isn't getting mounted before this function gets called.
  uint32_t lastScrollTime = 0;

// Start of Audio Definitions.
#define WAV_BUF_SIZE 512
  uint16_t wavBuf[WAV_BUF_SIZE * 2];

  // Because we access the relevant .wav file in multiple places. I got lazy and
  // made it a global.
  FIL wavFil;
  UINT bytesRead;
  FRESULT res;
  uint16_t spacing = 2;
  uint16_t h = Font_7x10.FontHeight;

  void playWav(char *filePath) {
    res = f_open(&wavFil, filePath, FA_READ);
    if (res != FR_OK) {
      return;
      myprintf("Failed to read file %s\n", filePath);
    }

    f_lseek(&wavFil, 44); // Skip WAV header
    f_read(&wavFil, &wavBuf, WAV_BUF_SIZE * 2, &bytesRead);
    // Start DMA for the full buffer (1024 bytes)
    myprintf("Beginning transmission of data for file\n");
    // No matter what I do here, this complains about the cast.
    HAL_SAI_Transmit_DMA(&hsai_BlockA1, (uint16_t *)wavBuf, WAV_BUF_SIZE);
  }

  /* USER CODE END 2 */

  /* Infinite loop */
  /* USER CODE BEGIN WHILE */
  while (1) {
    switch (GetCurrentSystemState()) {
    case SYSTEM_STATE_INIT: {
      static uint8_t mount_attempts = 0;
      myprintf("\r\n=== SD CARD CHECK ===\r\n");

      // Try to mount
      fres = f_mount(&FatFs, "", 1);

      if (fres == FR_DISK_ERR || fres == FR_NOT_READY) {
        // No card detected
        mount_attempts++;

        if (mount_attempts == 1) {
          // First attempt failed - show error
          myprintf("\r\n");
          myprintf("╔════════════════════════════════════════════════╗\r\n");
          myprintf("║          NO SD CARD DETECTED                   ║\r\n");
          myprintf("║                                                ║\r\n");
          myprintf("║  Please insert a microSD card                  ║\r\n");
          myprintf("║  Device will retry every 2 seconds...          ║\r\n");
          myprintf("╚════════════════════════════════════════════════╝\r\n");
          myprintf("\r\n");
          char SD_mount_err_buff1[18];
          char SD_mount_err_buff2[18];
          char SD_mount_err_buff3[18];
          char SD_mount_err_buff4[18];

          SH1106_Fill(SH1106_COLOR_BLACK);
          snprintf(SD_mount_err_buff1, sizeof SD_mount_err_buff1,
                   "NO SD CARD FOUND:");
          SH1106_GotoXY(1, 1 * (h + spacing));
          SH1106_Puts(SD_mount_err_buff1, &Font_7x10, 1);
          snprintf(SD_mount_err_buff2, sizeof SD_mount_err_buff2,
                   "TURN OFF DEVICE");
          SH1106_GotoXY(1, 2 * (h + spacing));
          SH1106_Puts(SD_mount_err_buff2, &Font_7x10, 1);
          snprintf(SD_mount_err_buff3, sizeof SD_mount_err_buff3,
                   "AND REINSERT SD");
          SH1106_GotoXY(1, 3 * (h + spacing));
          SH1106_Puts(SD_mount_err_buff3, &Font_7x10, 1);
          snprintf(SD_mount_err_buff4, sizeof SD_mount_err_buff4,
                   "TO CONTINUE");
          SH1106_GotoXY(1, 4 * (h + spacing));
          SH1106_Puts(SD_mount_err_buff4, &Font_7x10, 1);
          SH1106_UpdateScreen();

        } else {
          // Still waiting
          myprintf("Retry %d: Still no card detected...\r\n", mount_attempts);
        }

        // Blink LED while waiting
        HAL_GPIO_TogglePin(RED_LED_GPIO_Port, RED_LED_Pin);

        // Wait 2 seconds and retry
        HAL_Delay(2000);
        break; // Stay in INIT state
      }

      if (fres == FR_NO_FILESYSTEM) {
        myprintf("Card detected but not formatted as FAT32.\r\n");
        char SD_mount_err_buff1[18];
        char SD_mount_err_buff2[18];
        char SD_mount_err_buff3[18];
        char SD_mount_err_buff4[18];
        SH1106_Fill(SH1106_COLOR_BLACK);
        snprintf(SD_mount_err_buff1, sizeof SD_mount_err_buff1,
                 "SD CARD DETECTED:");
        SH1106_GotoXY(1, 1 * (h + spacing));
        SH1106_Puts(SD_mount_err_buff1, &Font_7x10, 1);
        snprintf(SD_mount_err_buff2, sizeof SD_mount_err_buff2,
                 "SD NOT FORMATTED");
        SH1106_GotoXY(1, 2 * (h + spacing));
        SH1106_Puts(SD_mount_err_buff3, &Font_7x10, 1);
        snprintf(SD_mount_err_buff3, sizeof SD_mount_err_buff3,
                 "AS FAT32, PLEASE");
        SH1106_GotoXY(1, 3 * (h + spacing));
        SH1106_Puts(SD_mount_err_buff3, &Font_7x10, 1);
        snprintf(SD_mount_err_buff4, sizeof SD_mount_err_buff4,
                 "REINSERT/REFORMAT");
        SH1106_GotoXY(1, 4 * (h + spacing));
        SH1106_Puts(SD_mount_err_buff4, &Font_7x10, 1);
        SH1106_UpdateScreen();
        Error_Handler();
      }

      if (fres != FR_OK) {
        myprintf("Mount error: %d\r\n", fres); // display
        char SD_mount_err_buff1[18];
        char SD_mount_err_buff2[18];
        char SD_mount_err_buff3[18];
        char SD_mount_err_buff4[18];
        SH1106_Fill(SH1106_COLOR_BLACK);
        snprintf(SD_mount_err_buff1, sizeof SD_mount_err_buff1,
                 "SD CARD MOUNT ERR");
        SH1106_GotoXY(1, 1 * (h + spacing));
        SH1106_Puts(SD_mount_err_buff1, &Font_7x10, 1);
        snprintf(SD_mount_err_buff2, sizeof SD_mount_err_buff2,
                 "SD MOUNT FAILED");
        SH1106_GotoXY(1, 2 * (h + spacing));
        SH1106_Puts(SD_mount_err_buff3, &Font_7x10, 1);
        snprintf(SD_mount_err_buff3, sizeof SD_mount_err_buff3,
                 "TRY TURNING OFF");
        SH1106_GotoXY(1, 3 * (h + spacing));
        SH1106_Puts(SD_mount_err_buff3, &Font_7x10, 1);
        snprintf(SD_mount_err_buff4, sizeof SD_mount_err_buff4,
                 "AND REINSERTING");
        SH1106_GotoXY(1, 4 * (h + spacing));
        SH1106_Puts(SD_mount_err_buff4, &Font_7x10, 1);
        SH1106_UpdateScreen();
        Error_Handler();
        //   Error_Handler();
      }

      // Success!
      myprintf("✓ SD card detected and mounted (attempt %d)\r\n",
               mount_attempts + 1); // display
      mount_attempts = 0;           // Reset for next time
      tsqFiles = sd_list_tsq_files(&tsqCount);
      myprintf(
          "###------------------   There are %d files on the SD CARD \n\r ",
          tsqCount);

      // Add config option to the menu
      PrependConfigOption(&tsqFiles, &tsqCount);
      myprintf("Menu initialized with %d total options (including config)\n\r",
               tsqCount);

      //			// Turn on green LED to indicate success
      //			HAL_GPIO_WritePin(RED_LED_GPIO_Port,
      //RED_LED_Pin, GPIO_PIN_RESET); 			HAL_GPIO_WritePin(GREEN_LED_GPIO_Port,
      //GREEN_LED_Pin, GPIO_PIN_SET);

      ChangeSystemState(SYSTEM_STATE_SEQUENCE_SELECT);
      break;
    }

    case SYSTEM_STATE_WAITING_CONFIG_INPUT: {
      // --- OLED Message Buffers (18 chars max per line) ---
      char oled_buf1[19];
      char oled_buf2[19];
      char oled_buf3[19];
      char oled_buf4[19];
      char oled_buf5[19];

      uint16_t spacing = 2;
      uint16_t h = Font_7x10.FontHeight; // 10

      // Get current windows
      const ScoringWindows *w = Scoring_GetWindows();

      // --- Display current config on OLED ---
      SH1106_Fill(SH1106_COLOR_BLACK);

      snprintf(oled_buf1, sizeof(oled_buf1), "Current Windows:");
      SH1106_GotoXY(1, 0 * (h + spacing) + TEXT_OFFSET_Y + LINE_TEXT_Y_OFFSET);
      SH1106_Puts(oled_buf1, &Font_7x10, 1);

      // Show P and G on one line
      snprintf(oled_buf2, sizeof(oled_buf2), "P:%u G:%u", w->perfect_radius_ms,
               w->good_radius_ms);
      SH1106_GotoXY(1, 1 * (h + spacing) + TEXT_OFFSET_Y + LINE_TEXT_Y_OFFSET);
      SH1106_Puts(oled_buf2, &Font_7x10, 1);

      // Show O and Po on next line
      snprintf(oled_buf3, sizeof(oled_buf3), "O:%u Po:%u", w->ok_radius_ms,
               w->poor_radius_ms);
      SH1106_GotoXY(1, 2 * (h + spacing) + TEXT_OFFSET_Y + LINE_TEXT_Y_OFFSET);
      SH1106_Puts(oled_buf3, &Font_7x10, 1);

      snprintf(oled_buf4, sizeof(oled_buf4), "Send SETWIN via");
      SH1106_GotoXY(1, 3 * (h + spacing) + TEXT_OFFSET_Y + LINE_TEXT_Y_OFFSET);
      SH1106_Puts(oled_buf4, &Font_7x10, 1);

      snprintf(oled_buf5, sizeof(oled_buf5), "UART or press X");
      SH1106_GotoXY(1, 4 * (h + spacing) + TEXT_OFFSET_Y + LINE_TEXT_Y_OFFSET);
      SH1106_Puts(oled_buf5, &Font_7x10, 1);

      SH1106_UpdateScreen();

      // --- Wait for UART input and get result ---
      myprintf("\r\nCurrent: P=±%u G=±%u O=±%u Po=±%u ms\r\n",
               w->perfect_radius_ms, w->good_radius_ms, w->ok_radius_ms,
               w->poor_radius_ms);
      myprintf(
          "Enter new config (SETWIN:P,G,O,Po) or press Enter to skip:\r\n> ");

      bool config_changed = Config_WaitForInput(); // Capture return value

      // --- Check if config was saved to flash ---
      bool saved_to_flash =
          config_changed; // Config_WaitForInput saves internally

      // Log to UART
      const ScoringWindows *w_after = Scoring_GetWindows();
      uart_buf_len =
          sprintf(uart_buf, "Current Windows: P=±%u G=±%u O=±%u Po=±%u\r\n",
                  w_after->perfect_radius_ms, w_after->good_radius_ms,
                  w_after->ok_radius_ms, w_after->poor_radius_ms);
      HAL_UART_Transmit(&huart2, (uint8_t *)uart_buf, uart_buf_len, 1000);

      // --- Display result on OLED ---
      SH1106_Fill(SH1106_COLOR_BLACK);
      memset(oled_buf1, 0, sizeof(oled_buf1));
      memset(oled_buf2, 0, sizeof(oled_buf2));
      memset(oled_buf3, 0, sizeof(oled_buf3));
      memset(oled_buf4, 0, sizeof(oled_buf4));
      memset(oled_buf5, 0, sizeof(oled_buf5));

      if (config_changed) {
        snprintf(oled_buf1, sizeof(oled_buf1), "Config Updated!");
        SH1106_GotoXY(1,
                      0 * (h + spacing) + TEXT_OFFSET_Y + LINE_TEXT_Y_OFFSET);
        SH1106_Puts(oled_buf1, &Font_7x10, 1);

        if (saved_to_flash) {
          snprintf(oled_buf2, sizeof(oled_buf2), "Saved to Flash.");
          SH1106_GotoXY(1,
                        1 * (h + spacing) + TEXT_OFFSET_Y + LINE_TEXT_Y_OFFSET);
          SH1106_Puts(oled_buf2, &Font_7x10, 1);
        } else {
          snprintf(oled_buf2, sizeof(oled_buf2), "Save FAILED.");
          SH1106_GotoXY(1,
                        1 * (h + spacing) + TEXT_OFFSET_Y + LINE_TEXT_Y_OFFSET);
          SH1106_Puts(oled_buf2, &Font_7x10, 1);

          snprintf(oled_buf3, sizeof(oled_buf3), "Using for now.");
          SH1106_GotoXY(1,
                        2 * (h + spacing) + TEXT_OFFSET_Y + LINE_TEXT_Y_OFFSET);
          SH1106_Puts(oled_buf3, &Font_7x10, 1);
        }

        // Display new values - split across two lines
        snprintf(oled_buf4, sizeof(oled_buf4), "P:%u G:%u",
                 w_after->perfect_radius_ms, w_after->good_radius_ms);
        SH1106_GotoXY(1,
                      3 * (h + spacing) + TEXT_OFFSET_Y + LINE_TEXT_Y_OFFSET);
        SH1106_Puts(oled_buf4, &Font_7x10, 1);

        snprintf(oled_buf5, sizeof(oled_buf5), "O:%u Po:%u",
                 w_after->ok_radius_ms, w_after->poor_radius_ms);
        SH1106_GotoXY(1,
                      4 * (h + spacing) + TEXT_OFFSET_Y + LINE_TEXT_Y_OFFSET);
        SH1106_Puts(oled_buf5, &Font_7x10, 1);

      } else {
        snprintf(oled_buf1, sizeof(oled_buf1), "No Changes Made");
        SH1106_GotoXY(1,
                      0 * (h + spacing) + TEXT_OFFSET_Y + LINE_TEXT_Y_OFFSET);
        SH1106_Puts(oled_buf1, &Font_7x10, 1);

        snprintf(oled_buf2, sizeof(oled_buf2), "Using current");
        SH1106_GotoXY(1,
                      1 * (h + spacing) + TEXT_OFFSET_Y + LINE_TEXT_Y_OFFSET);
        SH1106_Puts(oled_buf2, &Font_7x10, 1);

        snprintf(oled_buf3, sizeof(oled_buf3), "settings:");
        SH1106_GotoXY(1,
                      2 * (h + spacing) + TEXT_OFFSET_Y + LINE_TEXT_Y_OFFSET);
        SH1106_Puts(oled_buf3, &Font_7x10, 1);

        // Show current values
        snprintf(oled_buf4, sizeof(oled_buf4), "P:%u G:%u",
                 w_after->perfect_radius_ms, w_after->good_radius_ms);
        SH1106_GotoXY(1,
                      3 * (h + spacing) + TEXT_OFFSET_Y + LINE_TEXT_Y_OFFSET);
        SH1106_Puts(oled_buf4, &Font_7x10, 1);

        snprintf(oled_buf5, sizeof(oled_buf5), "O:%u Po:%u",
                 w_after->ok_radius_ms, w_after->poor_radius_ms);
        SH1106_GotoXY(1,
                      4 * (h + spacing) + TEXT_OFFSET_Y + LINE_TEXT_Y_OFFSET);
        SH1106_Puts(oled_buf5, &Font_7x10, 1);
      }

      SH1106_UpdateScreen();

      // --- Wait and return ---
      HAL_Delay(3000);
      ChangeSystemState(SYSTEM_STATE_SEQUENCE_SELECT);

      break;
    }

    case SYSTEM_STATE_SEQUENCE_SELECT: {
      // Poll buttons for navigation
      poll_buttons();
      selected_song = get_choose_song();
      scrolled = get_scrolled();
      rightPressed = get_press_right();
      selectedNewSong = get_selected_song();
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

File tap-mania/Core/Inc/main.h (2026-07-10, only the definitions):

#define SD_CD_Pin GPIO_PIN_13
#define SD_CD_GPIO_Port GPIOC
#define PB_U_Pin GPIO_PIN_0
#define PB_U_GPIO_Port GPIOA
#define PB_D_Pin GPIO_PIN_4
#define PB_D_GPIO_Port GPIOA
#define RED_PB_Pin GPIO_PIN_0
#define RED_PB_GPIO_Port GPIOB
#define RED_PB_EXTI_IRQn EXTI0_IRQn
#define GREEN_PB_Pin GPIO_PIN_1
#define GREEN_PB_GPIO_Port GPIOB
#define GREEN_PB_EXTI_IRQn EXTI1_IRQn
#define BLUE_PB_Pin GPIO_PIN_2
#define BLUE_PB_GPIO_Port GPIOB
#define BLUE_PB_EXTI_IRQn EXTI2_IRQn
#define PB_SEL_Pin GPIO_PIN_10
#define PB_SEL_GPIO_Port GPIOB
#define PB_SEL_EXTI_IRQn EXTI15_10_IRQn
#define SPI1_CS_Pin GPIO_PIN_11
#define SPI1_CS_GPIO_Port GPIOB
#define GREEN_LED_Pin GPIO_PIN_8
#define GREEN_LED_GPIO_Port GPIOA
#define RED_LED_Pin GPIO_PIN_9
#define RED_LED_GPIO_Port GPIOA
#define BLUE_LED_Pin GPIO_PIN_10
#define BLUE_LED_GPIO_Port GPIOA
#define YELLOW_LED_Pin GPIO_PIN_15
#define YELLOW_LED_GPIO_Port GPIOA
#define YELLOW_PB_Pin GPIO_PIN_4
#define YELLOW_PB_GPIO_Port GPIOB
#define YELLOW_PB_EXTI_IRQn EXTI4_IRQn
#define PB_R_Pin GPIO_PIN_5
#define PB_R_GPIO_Port GPIOB
#define PB_L_Pin GPIO_PIN_8
#define PB_L_GPIO_Port GPIOB
#define BEAT_LED_Pin GPIO_PIN_9
#define BEAT_LED_GPIO_Port GPIOB
#define SD_SPI_HANDLE hspi1
#define RED_COLUMN 0
#define GREEN_COLUMN 16
#define BLUE_COLUMN 32
#define YELLOW_COLUMN 48
#define ROW_INDEX 30
#define SECONDS_TO_MS 1000
#define CONSTANT 255
#define MAX_FILES 10
#define MAX_NAME_LEN _MAX_LFN + 1
#define NUM_ROWS 16
#define CLR_LINE "0000"
#define ROW_STRIDE 1
#define WIN_PERF 200
#define WIN_GOOD 300
#define WIN_OK 400
#define WIN_POOR 500 // 0 points inside this window; Miss if > 500
#define MAX_NOTES 64
#define LANES 2 // you have 2 buttons; adjust if more

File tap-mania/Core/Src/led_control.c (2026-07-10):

/**
 ******************************************************************************
 * @file           : led_control.c
 * @brief          : LED Control Functions Implementation
 ******************************************************************************
 */

#include "led_control.h"
#include "scoring.h"

extern LEDControl led_control;
extern uint32_t beat_led_on_tick;
extern uint32_t beat_led_off_tick;

/**
 * @brief Set LED state for a button
 */
void SetButtonLED(ArcadeButtonID button_id, bool state) {
  GPIO_PinState pin_state = state ? GPIO_PIN_SET : GPIO_PIN_RESET;

  switch (button_id) {
  case BUTTON_ID_GREEN:
    HAL_GPIO_WritePin(GREEN_LED_GPIO_Port, GREEN_LED_Pin, pin_state);
    break;
  case BUTTON_ID_RED:
    HAL_GPIO_WritePin(RED_LED_GPIO_Port, RED_LED_Pin, pin_state);
    break;
  case BUTTON_ID_BLUE:
    HAL_GPIO_WritePin(BLUE_LED_GPIO_Port, BLUE_LED_Pin, pin_state);
    break;
  case BUTTON_ID_YELLOW:
    HAL_GPIO_WritePin(YELLOW_LED_GPIO_Port, YELLOW_LED_Pin, pin_state);
    break;
  }

  led_control.led_is_on[button_id] = state;
}

/**
 * @brief Initialize LED control system
 */
void InitLEDControl(void) {
  for (int i = 0; i < BUTTON_COUNT; i++) {
    led_control.led_on_tick[i] = 0;
    led_control.led_off_tick[i] = 0;
    led_control.led_scheduled[i] = false;
    led_control.led_is_on[i] = false;
    SetButtonLED(i, false);
  }
  HAL_GPIO_WritePin(GREEN_LED_GPIO_Port, GREEN_LED_Pin, GPIO_PIN_RESET);
  HAL_GPIO_WritePin(RED_LED_GPIO_Port, RED_LED_Pin, GPIO_PIN_RESET);
  HAL_GPIO_WritePin(BLUE_LED_GPIO_Port, BLUE_LED_Pin, GPIO_PIN_RESET);
  HAL_GPIO_WritePin(YELLOW_LED_GPIO_Port, YELLOW_LED_Pin, GPIO_PIN_RESET);
  HAL_GPIO_WritePin(BEAT_LED_GPIO_Port, BEAT_LED_Pin, GPIO_PIN_SET);
  beat_led_on_tick = 0;
  beat_led_off_tick = 0;
}

/**
 * @brief Process scheduled LED events
 */
void ProcessLEDSchedule(void) {
  uint32_t current_tick = HAL_GetTick();

  for (int button = 0; button < BUTTON_COUNT; button++) {
    // Process ON Events
    if (led_control.led_scheduled[button]) {
      if (!led_control.led_is_on[button] &&
          led_control.led_on_tick[button] > 0 &&
          current_tick >= led_control.led_on_tick[button]) {

        SetButtonLED(button, true);
        led_control.led_on_tick[button] = 0;
        led_control.led_scheduled[button] = false;
      }
    }

    // Process OFF Events
    if (led_control.led_is_on[button] && led_control.led_off_tick[button] > 0 &&
        current_tick >= led_control.led_off_tick[button]) {

      SetButtonLED(button, false);
      led_control.led_off_tick[button] = 0;
    }
  }
}

/**
 * @brief Calculate timestamp for a future beat
 */
uint32_t CalculateBeatTimestamp(uint32_t beat_number, uint32_t current_beat_num,
                                uint32_t current_beat_timestamp_ms) {
  if (beat_number <= current_beat_num) {
    return current_beat_timestamp_ms;
  }

  extern volatile uint16_t current_bpm;
  uint32_t beats_ahead = beat_number - current_beat_num;
  uint32_t beat_period_ms = (60 * 1000) / current_bpm;
  return current_beat_timestamp_ms + (beats_ahead * beat_period_ms);
}
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

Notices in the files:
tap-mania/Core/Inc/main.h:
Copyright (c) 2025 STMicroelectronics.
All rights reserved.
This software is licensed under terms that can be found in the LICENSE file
